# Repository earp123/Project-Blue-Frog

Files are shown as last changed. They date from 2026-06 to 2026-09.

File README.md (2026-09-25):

# nRF5340 LoRa Field-Test Device (SX1262)

An open-source field-test device for **long-distance LoRa radio work**, built
around the Nordic **nRF5340** and a Semtech **SX1262** sub-GHz radio. It
currently hosts the radio layer of a sports-officials intercom: a fixed
4-slot TDMA broadcast flood in which every unit transmits once per frame and
hears everyone else.

Each unit pairs the radio with a local display and an SD card, so it is both
a link **endpoint** and an **instrument**: it runs timed soak tests, shows
live link telemetry, and logs every packet to SD for offline decoding. Build
two to four and you have a real multi-unit link to characterise in the field.

 

For the design history, measured results and known limitations, see
[CHANGELOG.md](CHANGELOG.md).

## Contents

- [Unit types](#unit-types)
- [Building and flashing](#building-and-flashing)
- [Using a unit](#using-a-unit)
- [Radio parameters](#radio-parameters)
- [LoRa radio shield (TFT unit)](#lora-radio-shield-tft-unit)
- [Rev 2 shield (shield unit)](#rev-2-shield-shield-unit)
- [TFT front end (TFT unit)](#tft-front-end-tft-unit)
- [SDK setup (fresh from Nordic)](#sdk-setup-fresh-from-nordic)

## Unit types

The tree builds one firmware per unit type. Both run the same TDMA radio
layer ([`src/tdma/`](src/tdma)) and the same SD soak logger, on an nRF5340
DK.

| Unit | Hardware | Firmware | Overlay + conf |
|---|---|---|---|
| **TFT unit** | Radio shield (rev 1) on Port 1, plus the Hiletgo ILI9341 TFT breakout (touch + microSD) jumper-wired to Port 0 | `CONFIG_APP_TDMA_CONSOLE`, [`src/tdma_console/`](src/tdma_console) | `boards/nrf5340dk_nrf5340_cpuapp_tft.{overlay,conf}` |
| **Shield unit** | Rev 2 shield: SX1262 + SSD1306 128×64 OLED + microSD in one stack | `CONFIG_APP_TDMA_FIELD`, [`src/tdma_field/`](src/tdma_field) | `boards/nrf5340dk_nrf5340_cpuapp_shield.{overlay,conf}` |

- **TFT unit:** touch + DK-button UI on the TFT. Display-only: no UART.
- **Shield unit:** button-only cycle-menu UI on the OLED. UART logging is on
  over the DK's VCOM.

The two types interoperate on air and can be mixed freely in one kit.

## Building and flashing

Each unit type needs **both** of its files, the overlay and the conf,
passed together. A build with only one of them, or neither, stops at CMake
with these two lines. Use `-p always` (pristine) when switching types.

```sh
# TFT unit
west build -b nrf5340dk/nrf5340/cpuapp -p always -d build-tft -- \
  -DEXTRA_DTC_OVERLAY_FILE=boards/nrf5340dk_nrf5340_cpuapp_tft.overlay \
  -DEXTRA_CONF_FILE=boards/nrf5340dk_nrf5340_cpuapp_tft.conf

# Shield unit
west build -b nrf5340dk/nrf5340/cpuapp -p always -d build-shield -- \
  -DEXTRA_DTC_OVERLAY_FILE=boards/nrf5340dk_nrf5340_cpuapp_shield.overlay \
  -DEXTRA_CONF_FILE=boards/nrf5340dk_nrf5340_cpuapp_shield.conf
```

The board-named radio overlay (`nrf5340dk_nrf5340_cpuapp.overlay`) is applied
automatically in both builds.

Flash with the DK's J-Link serial number when more than one board is on USB
(`nrfutil device list` shows them):

```sh
west flash -d build-shield --dev-id <serial>
```

> [!NOTE]
> A DK that arrives with readback protection (APPROTECT) refuses to attach.
> `west flash --recover` fixes it once, and **erases all flash on both
> cores**. These builds leave debug access open, so later flashes work
> normally. `west flash` defaults to the `nrfutil` runner, which needs its
> `device` command (`nrfutil install device`); `-r jlink` also works.

## Using a unit

Both types behave the same way:

- **Power-on unit pick (mandatory).** Choose **MASTER** (slot 0) or **SEC 1**,
  **SEC 2** or **SEC 3**. This sets the role and the TX slot together. The
  master beacons the frame timing, and each secondary locks to it. Every
  unit in a kit needs its own slot. The choice holds until reboot. The TFT
  unit runs a touch calibration first.
- **SOAK:** pick 5 min, 30 min, 2 h or continuous. Live pages show elapsed
  time, TX/stale, RX with missed/duplicate frames, phase error and ppm,
  RSSI/SNR, the log file, and the staging-latency gauge.
- **TX power:** −9…+22 dBm, applied from the next packet. The TFT unit boots
  at +22 dBm and the shield unit at +0 dBm.
- **SD logging:** every soak writes `<PWR>_<DUR>_NNN.BIN` (e.g.
  `P0_5M_000.BIN`) with one 64-byte record per packet. Decode with
  [`src/tdma_console/tools/decode_soak_log.py`](src/tdma_console/tools/decode_soak_log.py).
  Each file's header records the unit's role and slot.
- **Buttons:** B1 = UP, B2 = DOWN, B3 = OK, B4 = BACK. On the shield unit, B4
  also stops a running soak.

> [!IMPORTANT]
> **Reboot after swapping an SD card.** Card detect is read by the app only,
> so a card changed while mounted is never re-initialised, and every write
> then fails. The shield unit's socket is push-push: it makes no contact
> until it clicks.

## Radio parameters

Fixed in [`src/tdma/tdma.h`](src/tdma/tdma.h); only TX power is adjustable
at runtime.

- Frequency: 915.0 MHz, single channel
- LoRa SF5 / BW 500 kHz / CR 4/5, explicit header, CRC on
- Preamble: 12 symbols (the SX1262 minimum for SF5)
- Packet: 44 bytes (4-byte TDMA header + 40-byte payload), 7,760 µs on air
- Frame: 4 slots × 20 ms = 80 ms. Master in slot 0, secondaries in 1–3.

---

## LoRa radio shield (TFT unit)

The SX1262 (Wio-SX1262) is mounted on a custom Arduino-form-factor shield that
routes its signals to the nRF5340 DK Port 1 header section. The rev 2 shield
keeps exactly the same radio pins.

### Wiring (nRF5340 DK → Wio-SX1262)

| Signal | nRF5340 pin | Wio-SX1262 pin |
| --- | --- | --- |
| SPI SCK  | P1.05 | SCK |
| SPI MOSI | P1.04 | MOSI |
| SPI MISO | P1.01 | MISO |
| SPI CS | P1.07 | NSS |
| RESET | P1.06 | RESET |
| BUSY | P1.09 | BUSY |
| DIO1 | P1.08 | DIO1 |
| RF_SW | P1.00 | RF_SW |
| VCC | 3V3 | VCC (+ 33µF cap) |
| GND | GND | GND |

Notes:

- **RF_SW** (P1.00) is driven by the firmware as a GPIO output and held LOW
  (at GND) for both TX and RX on this module. This is the correct level for the
  Wio-SX1262 antenna switch — it does not need to be toggled.
- **DIO2** is internally bridged to TXEN on the Wio-SX1262 — no external wiring.
  `dio2-tx-enable` in the overlay lets the chip drive TXEN itself.
- **DIO3** drives the onboard TCXO — no external wiring; configured via
  `dio3-tcxo-voltage`.
- **uart1** is disabled in the overlay so that P1.01 is free for MISO.
- **33µF decoupling capacitor** on the Wio-SX1262 VCC pin is required. The TX
  current transient on the SX1262 power amplifier causes a supply droop
  sufficient to cause intermittent TX failures without it.

Devicetree (`nrf5340dk_nrf5340_cpuapp.overlay`, SX1262 node):

```dts
lora: sx1262@0 {
    compatible = "semtech,sx1262";
    reg = <0>;
    reset-gpios    = <&gpio1 6 GPIO_ACTIVE_LOW>;
    busy-gpios     = <&gpio1 9 GPIO_ACTIVE_HIGH>;
    dio1-gpios     = <&gpio1 8 GPIO_ACTIVE_HIGH>;
    dio2-tx-enable;
    dio3-tcxo-voltage = <SX126X_DIO3_TCXO_1V8>;
    tcxo-power-startup-delay-ms = <10>;
    spi-max-frequency = <500000>;
};
```

The radio is selected through the `lora0` alias; `RF_SW` is exposed via the
`zephyr,user` node's `rf-sw-gpios` property (P1.00). The native Zephyr driver
only initialises the chip; the TDMA layer owns it after that.

---

## Rev 2 shield (shield unit)

One Arduino-form-factor board carrying the Wio-SX1262 (same pins as above),
a 0.96" SSD1306 OLED and a push-push microSD socket. Fabrication data:
[`Hardware/OLED-SD-SX1262-Shield_2026-08-16.zip`](Hardware/OLED-SD-SX1262-Shield_2026-08-16.zip).
All pins were traced in its netlist and confirmed on the bench.

| Device | Bus | Pins (DK Arduino header) |
|---|---|---|
| microSD | spi4 | SCK **P1.14** (D12), MOSI P1.13 (D11), MISO **P1.15** (D13), CS P1.11 (D9), card-detect P1.12 (D10, active low) |
| SSD1306 128×64 | i2c1 @ 400 kHz | SDA P0.25 (A4), SCL P0.26 (A5), RST P0.07 (A3), address 0x3C |

- **SD SCK/MISO are the reverse of the DK's own `arduino_spi`.** That is how
  the board is routed.
- **The OLED is on A4/A5.** The R3 header's dedicated SDA/SCL pins are not
  connected.
- **No I2C pull-ups on the shield.** The overlay enables the nRF's internal
  ones as a fallback.
- **The I2C driver's concat buffer is raised to 1025 bytes** (a control byte
  plus a full frame). With the 16-byte default, every frame write fails and
  the screen stays blank.

---

## TFT front end (TFT unit)
[https://a.co/d/047jULLv](url)
The TFT unit's front end — ILI9341 TFT, XPT2046 touch, microSD — shares one
SPI bus (**spi4**, the DK's high-speed `arduino_spi` instance on Port 0),
distinct from the radio's spi2 on Port 1. Each device has its own chip
select. **These signals are jumper-wired to the DK Arduino headers.**

### Pin assignments

| Signal | nRF5340 pin | Device pin |
| --- | --- | --- |
| SPI SCK | P0.13 | SCK (all) |
| SPI MOSI | P0.14 | MOSI/SDI (all) |
| SPI MISO | P0.15 | MISO/SDO (all) |
| LCD CS | P0.16 | ILI9341 CS |
| LCD D/C | P0.17 | ILI9341 D/C |
| LCD RESET | P0.18 | ILI9341 RESET |
| LCD backlight | P0.31 | Backlight (active high) |
| TOUCH CS | P0.28 | XPT2046 CS |
| TOUCH IRQ | P0.29 | XPT2046 IRQ (active low, pull-up)|
| SD CS | P0.10 | microSD CS |

CS lines are indexed by each device's `reg` on the spi4 node: reg 0 = display
(P0.16), reg 1 = touch (P0.28), reg 2 = SD (P0.10).

> [!IMPORTANT]
> **nRF5340 DK board modifications required.** Several of these Port 0 pins are
> wired to on-board peripherals on the DK and must be freed before the front end
> works. The relevant solder bridges are marked on the DK silkscreen (and
> detailed in the nRF5340 DK Hardware User Guide); the exact `SBxx` designators
> vary by board revision.
>
> - **SPI bus — P0.13–P0.18 are shared with the on-board QSPI flash** (MX25R64).
>   SPI SCK/MOSI/MISO and LCD CS / D-C / RESET land on the flash's
>   `QSPI_IO0/IO1/IO2/IO3` + `QSPI_SCK`/`QSPI_CSN`, so the flash must be
>   **disconnected** (cut its solder bridges) — otherwise it loads and contends on
>   the shared bus.
> - **P0.28–P0.31 are the four on-board LEDs** (LED1–LED4). The front end uses
>   P0.28 (touch CS), P0.29 (touch IRQ), and P0.31 (backlight); P0.30 (LED3) is
>   unused. Isolate these LEDs from the GPIOs (per the silkscreen bridges) so the
>   on-board LEDs don't interfere with the touch/backlight lines.
>
> The four DK buttons (P0.23/24/08/09) are **not** modified — they still drive the
> menu UI.

### Implementation notes / deviations

- **Touch binding is** `xptek,xpt2046` (not `ti,tsc2046`) in this Zephyr. It
  reports via the input subsystem (`INPUT_ABS_X/Y`, `INPUT_BTN_TOUCH`); the
  IRQ is edge-to-active (falling, `GPIO_ACTIVE_LOW | GPIO_PULL_UP`).
- **ILI9341 RESET is active-low.** The MIPI-DBI driver leaves reset de-asserted
  after its pulse, so `reset-gpios` must be `GPIO_ACTIVE_LOW` — otherwise the
  panel is held in reset and stays blank even though SPI writes "succeed".
- **CFB cannot drive the ILI9341.** Zephyr's character framebuffer is
  monochrome-only (1 bpp); the ILI9341 is RGB565/RGB888. The app enables CFB only
  to link its (correct) bundled font glyph data, then blits that into RGB565
  itself with `display_write()` (white/black, byte-order agnostic).
- The display uses the **MIPI DBI** subsystem: a `zephyr,mipi-dbi-spi`
  controller wraps spi4 and owns the D/C and RESET sidebands; the
  `ilitek,ili9341` node sits under it.
- **Drawing stays single-owner.** Input callbacks only set atomics; the main
  loop does every `display_write()`. Touch taps are debounced (one event per
  press, release required) before the loop consumes them.
- **Touch is calibrated by an on-device affine fit**
  (`src/tdma_console/touch_cal.c`). Raw XPT2046 coordinates are offset /
  swapped / inverted relative to the display; a 6-parameter affine corrects
  all of it at once. Calibration is a mandatory power-on step: five crosshair
  taps, a least-squares fit, then a verify step. The fit lives in RAM only.

---

## SDK setup (fresh from Nordic)

This project uses the **native** Zephyr SX126x LoRa driver
(`CONFIG_LORA_MODULE_BACKEND_NATIVE` / `CONFIG_LORA_SX126X_NATIVE`), which is
**not part of stock NCS v3.2.1**. Two repo assets close that gap so the project
builds against a clean SDK:

- `external/zephyr-lora-driver/` — the newer Zephyr `drivers/lora/`
  subsystem (incl. the native SX126x driver), vendored verbatim.
- `patches/` — small compat patches: SPI macro arity (`0001`), the
  `regulator-ldo` / `force-ldro` binding properties (`0002`), and the newer
  `lora.h` API the driver expects (`0003`).

### Onboarding (what to do with a fresh Nordic SDK)

1. Install **NCS v3.2.1 + toolchain** via nRF Connect for Desktop → *Toolchain
   Manager* (provides `west`, CMake, Ninja, the Zephyr SDK/GCC). Install
   **SEGGER J-Link** too (the DK's on-board debugger).

2. Prepare the SDK from this repo (idempotent; defaults `ZEPHYR_BASE` to
   `C:/ncs/v3.2.1/zephyr`):

   ```sh
   ZEPHYR_BASE=/path/to/ncs/zephyr ./scripts/setup_sdk.sh
   ```

   This swaps the vendored `drivers/lora/` into the SDK (backing up the stock
   one to `drivers/lora.stock.bak`) and applies the patches.

3. Build one of the two unit types and flash it, as shown in
   [Building and flashing](#building-and-flashing).

**Symptoms if the SDK was not prepared:**

- `macro "SPI_DT_SPEC_INST_GET" requires 3 arguments, but only 2 given`
- `'..._P_regulator_ldo' undeclared` / `'..._P_force_ldro' undeclared`
- silently building the wrong LoRa backend (the native `CONFIG_*` symbols
  don't exist on a clean SDK and are dropped with a warning)

> [!WARNING]
> These changes live in the NCS install, not in this repo. Any `west update`,
> SDK reinstall, or Toolchain Manager repair reverts them — just re-run
> `scripts/setup_sdk.sh` and do a pristine build. Patch 2 changes a
> devicetree binding, which is only picked up on a CMake reconfigure
> (`-p always`).

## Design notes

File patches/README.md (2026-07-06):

# Vendored NCS SDK patches

These patches make this project's **native SX126x LoRa driver** build against
**NCS v3.2.1**. They modify files **inside the NCS install** (`$ZEPHYR_BASE`),
not this repository — so they are vendored here and applied with a script.

## Apply

> [!TIP]
> **New here?** Run [`scripts/setup_sdk.sh`](../scripts/setup_sdk.sh) instead — it
> installs the vendored driver *and* runs `apply.sh` for you. Use `apply.sh`
> directly only to re-apply the patches when the native driver is already present
> (see [Prerequisite](#prerequisite-the-vendored-lora-driver) below).

```bash
# defaults ZEPHYR_BASE to C:/ncs/v3.2.1/zephyr
ZEPHYR_BASE=/path/to/ncs/zephyr ./patches/apply.sh
```

The script is idempotent (skips already-applied patches) and uses `git apply`
against the NCS `zephyr/` checkout. After applying, do a **pristine** build
(`west build -p always`) — Patch 2 changes a devicetree binding, which is only
picked up on a CMake reconfigure.

## What they fix

`west build` fails without these with:

- `macro "SPI_DT_SPEC_INST_GET" requires 3 arguments, but only 2 given`
- `'..._P_regulator_ldo' undeclared` / `'..._P_force_ldro' undeclared`
- `'SF_5' undeclared` / `'BW_7_KHZ' undeclared` /
  `'struct lora_modem_config' has no member named 'packet_crc_disable'` /
  `'struct lora_driver_api' has no member named 'recv_duty_cycle_async'`

| File | Patch | Why |
|---|---|-----|
| `0001-native-sx126x-spi-dt-spec-arity.patch` | adds the trailing `delay` arg (`0`) to both `SPI_DT_SPEC_INST_GET` calls in `drivers/lora/native/sx126x/sx126x.c` | the native driver uses the newer 2-arg SPI macro; v3.2.x's `spi.h` requires 3 args |
| `0002-sx126x-base-binding-add-ldo-props.patch` | adds the `regulator-ldo` and `force-ldro` boolean properties to `dts/bindings/lora/semtech,sx126x-base.yaml` | the native driver reads these DT props, which don't exist in v3.2.x's binding |
| `0003-lora-h-native-driver-api-compat.patch` | brings `include/zephyr/drivers/lora.h` up to the newer upstream API the vendored driver was written against: `SF_5`, the narrow `BW_*` enum members, `packet_crc_disable`, and the `recv_duty_cycle_async`/`airtime` driver-API slots + inline wrappers | stock v3.2.x ships the older LoRa API header; the vendored driver **and this project's app sources** (`SF_5` etc.) don't compile against it |

Note: `apply.sh` passes `--ignore-whitespace` to `git apply`. On Windows the
repo checkout is CRLF (`.gitattributes` `text=auto`), so the driver files
`setup_sdk.sh` copies into the SDK carry CRLF while the patches are LF;
without the flag none of the patches match their context.

## Prerequisite: the vendored LoRa driver

These patches assume the **newer native LoRa driver is present** in the SDK
(`drivers/lora/native/`). That driver is **not** part of stock NCS v3.2.1, so it
is vendored in `../external/zephyr-lora-driver/` and installed by
`../scripts/setup_sdk.sh`, which copies it into `$ZEPHYR_BASE/drivers/lora` and
*then* runs `apply.sh`.

**For a fresh-from-Nordic SDK, run `scripts/setup_sdk.sh` — not `apply.sh`
directly.** `setup_sdk.sh` does the driver swap first; `apply.sh` only patches
and will refuse to run if the native driver is absent.

## Caveat: these revert on SDK changes

Any `west update`, SDK reinstall, or Toolchain Manager repair reverts these
edits **and the vendored driver swap**. Re-run
[`scripts/setup_sdk.sh`](../scripts/setup_sdk.sh) afterward — running `apply.sh`
alone is not enough, since it refuses once the native driver is gone.

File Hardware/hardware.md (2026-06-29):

hardware entry file

Pictured in the readme. I spun these shields at OSH Park and assembled the radio chip by hand.

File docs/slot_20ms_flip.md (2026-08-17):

# Task: flip `TDMA_SLOT_DURATION_US` to 20 ms + acceptance soak

**Status:** ready. **Decisions (2026-08-16):** straight constant flip (no runtime
selector first); `frame_ctr` wrap fix deferred — soaks at 20 ms capped under
1.4 h; units 3/4 not yet available — this task validates on the 2-unit bench,
the 4-unit soak and field campaign are gated on hardware.

## The change

`src/tdma/tdma.h`:

```diff
-#define TDMA_SLOT_DURATION_US	50000
+#define TDMA_SLOT_DURATION_US	20000
```

Everything else derives or is width-independent, verified at head:

| Constant | At 20 ms | Check |
|---|---|---|
| `TDMA_FRAME_DURATION_US` | 80 ms (derived, 4 slots) | beacon cadence 12.5 Hz |
| `TDMA_SLOT_ACTIVE_US` | 18 ms (derived, 90%) | > 8.3 ms worst in-slot completion (532 + 7760) — TX timeout only, RX is continuous |
| `TDMA_TOA_US`, `TDMA_TX_START_LATENCY_US` | unchanged | width-independent; `dtx` = 8292 µs is the regression check |
| `TDMA_SYNC_STEP_CLAMP_US` | 500 µs **per 80 ms frame** | max slew 6.25 ms/s (was 2.5) — intended, no change |
| `TDMA_RX_MSGQ_DEPTH` | 32 | header comment already sizes this for the 20 ms 4-unit case |

## Pre-flight audit (before flashing)

1. Confirm every `tdma_config.slot_duration_us` initializer in the app variants
   passes the macro, not a literal — `tdma_init()` rejects a mismatch.
2. Comment touch-up in `tdma.h`: the per-slot tallies comment says "the
   programmed 45 ms" (the 50 ms-era `SLOT_ACTIVE`); make it width-neutral.
   The `TDMA_SLOT_DURATION_US` comment's "test-build / production target"
   framing inverts with the flip — update it.
3. No soak-preset code change. Constraint recorded instead: at 20 ms the
   counter wraps at **1.46 h**. Within-file continuity is wrap-safe (modular
   deltas); absolute cross-file alignment past a wrap is not. Until the wrap
   card closes: use the 5 min / 30 min / 1 h-equivalent presets for anything
   needing cross-file pairing; a continuous run is valid but only
   pairwise-alignable up to the first wrap.

## Acceptance soak

30 min preset, 20 ms slots, both bench units, +0 dBm (same as the 250 µs
threshold soak, for comparability), SD-logged both sides, decode both files.

Rate sanity: 2 units at 80 ms frames = 1 TX + 1 RX record per frame per unit
= 25 rec/s = 1.6 KB/s — half the SD budget.

**Pass criteria** (50 ms baselines in parentheses):

- Lock: SYNCING → RUNNING within single-digit seconds (2.3 s). The one
  failure mode the one-way transition allows is *slow or absent lock* — a
  unit stuck in SYNCING fails the soak regardless of anything else.
- `dtx` = 8292 ± tens of µs, **both roles** (8292 exactly); `drx` collapses
  to the same value on both (8290/8291).
- `phase_err`: median ≈ 0, p95 |err| ≤ 50 µs (24 µs), worst |err| < 125 µs —
  half the 250 µs bar. Beacons arrive 2.5× more often, so equal-or-tighter
  is the expectation; growth toward the bar is a red flag even if it locks.
- Link: PER 0.000%, 0 missed / 0 dup, 0 `seq` gaps, `stale_retx` /
  `busy_timeouts` / `slot_timeouts` all 0 (all match the 11-min baseline).
- `ppm`: mean within a few ppm of −6.9 (same crystal pair). Per-sample σ up
  to ~170 is *expected*, not a regression — the estimator divides the same
  ±13 µs timestamp jitter by an 80 ms frame instead of 200 ms. The mean is
  the signal.

## Out of scope / gated

- **4-unit soak**: gated on building units 3 and 4. The open re-validation
  question (three peer slots between corrections during acquisition) can only
  be answered there.
- **Field campaign at 20 ms**: after the 4-unit bench soak.
- **`frame_ctr` widen/unwrap** and **runtime slot-width selector**: separate
  cards, unchanged by this task.

## CHANGELOG

New entry: slot width 50 → 20 ms with the soak results and the pass/fail
table above; note the 1.4 h soak-duration constraint at 20 ms and reference
the wrap limitation. Update the "what remains before calling 20 ms proven"
line to: 4-unit soak (hardware pending) + field campaign.

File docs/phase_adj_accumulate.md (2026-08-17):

# Task: make `tdma_port_add_phase_adj()` accumulate

**Status:** ready for implementation. **Scope:** one semantic fix + comment updates + CHANGELOG. No behavior change for the current call pattern.

## Context

`tdma_port_add_phase_adj()` in `src/tdma/tdma_port.c` is named "add" but implements *set*:

```c
void tdma_port_add_phase_adj(int32_t adj_us)
{
	atomic_set(&phase_adj_us, adj_us);
}
```

The consumer is `slot_alarm_cb()`, which folds the entire pending value into one boundary:

```c
next_target += slot_ticks + (uint32_t)atomic_clear(&phase_adj_us);
```

With overwrite semantics, any second post before the next boundary silently discards the first. This is **latent today**: `tdma_core_sync_feed()` posts exactly one correction per beacon (one per frame), and boundaries consume 4x per frame, so there is never more than one outstanding value — set and add are currently indistinguishable. It becomes a real bug the moment two posts can land between consumptions (a slew-limited loop splitting a large error into partial steps, or a drift/ppm feed-forward writer added alongside the beacon correction — both on the table for the M3 filter work). A dropped correction self-heals at the next beacon but is transiently wrong; at 20 ms slots with `TDMA_SYNC_LOCK_ERR_US` tightened to ~250 us, a dropped ms-scale correction can bounce a unit out of RUNNING.

## Change

`src/tdma/tdma_port.c`:

```diff
 void tdma_port_add_phase_adj(int32_t adj_us)
 {
-	atomic_set(&phase_adj_us, adj_us);
+	atomic_add(&phase_adj_us, adj_us);
 }
```

Notes for the implementer:

- **Behavior-identical for the current single-post pattern**: adding to a zeroed pending value equals setting it. The acquisition snap (`fwd` up to one frame) and the steady-state clamped step both still apply in full at the next boundary.
- **Race with the consumer is benign under add**: a post either lands before the ISR's `atomic_clear` (applied at this boundary) or after (pending for the next). Nothing is ever lost. This was also true under set for a single writer; add extends the guarantee to any number of posts.
- The `(uint32_t)` cast on the consumer side stays — negative adjustments work through two's-complement wraparound on the unsigned add, as today.
- `tdma_port_schedule_start()` already zeroes `phase_adj_us` before arming; unchanged.

## Comment updates (same commit)

1. `src/tdma/tdma_port.h` — the contract comment on `tdma_port_add_phase_adj()`: state that corrections **accumulate** into a single pending value consumed in full at the next slot boundary, and that multiple posts between boundaries sum.
2. `src/tdma/tdma_port.c` — the `slot_alarm_cb()` block comment currently reads "A pending sync correction is folded in once." Amend to: pending corrections accumulate and the sum is folded in once.

## Explicitly out of scope

**No consumption-side per-boundary clamp.** Post-side clamping already exists where it matters: the steady-state step is clamped to `+/-TDMA_SYNC_STEP_CLAMP_US` at the call site in `tdma_core_sync_feed()`, and the acquisition snap is deliberately unclamped and forward-only (see its comment — a clamped loop would take tens of seconds to pull in a worst-case offset, and forward-only guarantees the alarm target never lands in the past). Slewing the snap at the consumer would fight that design. A per-boundary application clamp belongs with the M3 sync-filter rework (`TODO(M3+)` in `tdma_core_sync_feed()`), where multiple partial posts per frame become a real pattern.

## Verification

1. Build the TDMA field console variant; flash both bench units.
2. Cold start: secondary acquires and locks in the usual ~6 s (snap behavior unchanged).
3. 10+ min soak at 50 ms: `ph` converges to single-digit us as before; `dtx`/`drx` hold ~8292 us; no new `stale_retx` or slot timeouts.
4. Behavior must be indistinguishable from the previous build — this change is semantic future-proofing, not a tuning change.

## CHANGELOG

Mark the 2026-07-21 open item ("`tdma_port_add_phase_adj()` overwrites rather than accumulates a pending correction") resolved with the date, and note the accumulate semantics under a new entry. This is step 3 (first half) of the 50 ms -> 20 ms tightening sequence; the `TDMA_SYNC_LOCK_ERR_US` tightening to ~250 us follows as a separate change once this soaks clean.

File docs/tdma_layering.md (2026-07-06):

# TDMA layering findings (M0)

Verification record for the intercom TDMA variant's four-layer architecture:
what the native driver (L0) actually does, how the app-owned command layer
(L1) and TDMA engine (L2) coexist with it, and what was found when auditing
the driver for autonomous runtime behaviour. File/line references are into
the vendored driver (`external/zephyr-lora-driver/drivers/lora/native/sx126x/`),
which is byte-identical to the installed copy under `$ZEPHYR_BASE/drivers/lora`
(modulo line endings) by construction of `scripts/setup_sdk.sh`.

## Where the native driver landed on this machine

- SDK in use: **NCS v3.2.0** at `C:/ncs/v3.2.0/zephyr` (the repo README says
  v3.2.1; this machine has v3.2.0 and v3.3.0 installed, and the nRF Connect
  toolchain bundle `66cdf9b75e` serves both v3.2.0 and v3.2.1). Set
  `ZEPHYR_BASE=C:/ncs/v3.2.0/zephyr` when running `scripts/setup_sdk.sh`.
- The vendored `drivers/lora` tree was already installed there, but the
  compat patches were **not** applied — `git apply` refused them because the
  Windows checkout (`.gitattributes` `text=auto`) copies CRLF files into the
  SDK while the patches are LF. `patches/apply.sh` now passes
  `--ignore-whitespace`, which resolves this; it also globs all numbered
  patches instead of naming 0001/0002.
- Stock NCS v3.2.0's `include/zephyr/drivers/lora.h` predates the vendored
  driver and lacks `SF_5`, the narrow `BW_*` members, `packet_crc_disable`,
  and the `recv_duty_cycle_async`/`airtime` API slots. **No variant of this
  project compiled against it.** New patch
  `patches/0003-lora-h-native-driver-api-compat.patch` brings the header up
  to what the vendored driver (and the existing console/lora-send sources)
  expect, mirroring the newer upstream layout. All three firmware variants
  build after `setup_sdk.sh`.

## L0 driver: DIO1 mechanism and the detach

The driver's interrupt path (the one autonomous runtime SPI path):

- `sx126x_hal_init()` registers a `struct gpio_callback` on the DIO1 pin:
  `gpio_init_callback(&data->dio1_cb, dio1_isr, ...)` + `gpio_add_callback()`
  (`sx126x_hal.c:160-161`). The callback struct lives in driver data:
  `((struct sx126x_data *)dev->data)->hal.dio1_cb` (`sx126x_hal.h:41-45`,
  `sx126x.h:35-36`).
- `dio1_isr` forwards to `data->dio1_callback`, which the driver sets to
  `sx126x_dio1_callback` (`sx126x.c:1479`); that handler does
  `k_work_submit(&data->irq_work)` (`sx126x.c:559-564`) and
  `sx126x_irq_work_handler` performs **SPI transactions on the system
  workqueue** (`sx126x.c:800-834`) — exactly the violation of L2's sole-SPI-
  ownership invariant that had to be neutralized.

**Detach method used:** `gpio_remove_callback()` on the driver's callback
struct, which *is* reachable — `tdma_radio.c` includes the driver-internal
`sx126x.h` (include path added in `CMakeLists.txt` pointing at the installed
copy in `$ZEPHYR_BASE`) and removes `&drv_data->hal.dio1_cb` from the DIO1
port, then registers the TDMA port's own callback and re-enables the pin
interrupt. No `patches/0003`-style detach hook was needed for this. After
removal the driver cannot regain the pin: `gpio_add_callback` for its struct
only happens in `sx126x_hal_init()` (device init), and
`sx126x_hal_set_dio1_callback()` only flips the function pointer and the pin
interrupt config, not the callback registration.

Ordering (in `tdma_radio_init()`): `device_is_ready()` → `lora_config()` →
detach + attach → remaining L1 init → `k_sem_give(&tdma_spi_bus_sem)`. The
radio thread's first act is taking that semaphore, held forever.

## Does `lora_config()` calibrate the image post-TCXO?

**Yes.** `sx126x_chip_init()` (driver device init) configures the TCXO via
DIO3 and runs `Calibrate(ALL)` after it (`sx126x.c:476-490`), and
`sx126x_lora_config()` additionally runs `sx126x_calibrate_image(dev,
config->frequency)` on every call (`sx126x.c:878-882`) with the correct
902-928 MHz band bytes (0xE1/0xE9) for 915 MHz (`sx126x.c:218-220`). L1
therefore does **not** re-issue `CalibrateImage` at init;
`sx126x_cmd_calibrate_image()` exists in L1 for completeness.

## Autonomous-quiescence audit of the driver after init

Checked the whole vendored native driver for anything that could touch the
SPI bus or radio state without an explicit `lora_*` API call:

| Path | Finding |
| --- | --- |
| DIO1 `gpio_callback` → `k_work irq_work` | The one real violation; detached at init (above). `irq_work` is only ever submitted from the DIO1 callback (`sx126x.c:563`), so with the callback removed the work item is dead. |
| `k_timer` / delayed work | None in the driver. |
| PM hooks | `sx126x_pm_action` exists only under `CONFIG_PM_DEVICE` (`sx126x.c:1439-1453`), which is **off** in this build (verified in `.config`); it also only touches GPIOs, not SPI. |
| LoRa shell | `drivers/lora/shell.c` issues runtime `lora_*` calls, but `CONFIG_LORA_SHELL` is **off** (defaults n; the TDMA variant's `select SHELL` does not enable it — verified in `.config`). |
| Sleep-when-idle | `CONFIG_LORA_SX126X_NATIVE_SLEEP` **defaults y** and would have `lora_config()` put the chip to sleep on return (and detach/re-attach DIO1 on its own). The app Kconfig forces it **n** for `APP_TDMA_TEST`, so `lora_config()` returns with the chip in STDBY_RC, configured, and the driver idle. |

Conclusion: after `tdma_init()` completes, the only ways the driver could run
are `lora_*` API calls, which L2 never makes past init. The invariant is
temporal and now holds.

## `sx126x_cmd` (L1) devicetree wiring

`sx126x_cmd.c` resolves its own specs from the same `lora0` node
(`DT_ALIAS(lora0)` → `&lora` on spi2, per the auto-applied
`nrf5340dk_nrf5340_cpuapp.overlay`):

- `SPI_DT_SPEC_GET(RADIO_NODE, SPI_WORD_SET(8) | SPI_TRANSFER_MSB, 0)` —
  same word size/order/CS behaviour as the driver, 500 kHz per the overlay's
  `spi-max-frequency`. The Zephyr SPI subsystem serializes bus users, so
  L0-at-init and L1-at-runtime sharing spi2 is safe.
- `GPIO_DT_SPEC_GET(RADIO_NODE, busy_gpios)` (P1.09) — all BUSY gating lives
  in L1: every transaction is preceded by a bounded BUSY-low spin
  (`sx126x_cmd_wait_busy`, 20 ms budget, timeout is fatal to the engine and
  counted as `busy_timeouts`).
- `GPIO_DT_SPEC_GET(RADIO_NODE, dio1_gpios)` (P1.08) — exported to the port
  layer for the IRQ handover.
- RF_SW (P1.00, `zephyr,user` `rf-sw-gpios`) is configured output-LOW first
  thing in `tdma_radio_init()`, same as the console and lora-send variants.

Init details beyond the plan's M0 list, found necessary while verifying the
driver:

- The DS §15.1 TX-modulation workaround for 500 kHz BW (clear bit 2 of reg
  0x0889) is applied by the driver only in its send path, which is never
  called — L1 applies it once at init; the radio never sleeps so it sticks.
- The driver programs a 200 µs PA ramp in `lora_config()`; L1 re-issues
  `SetPaConfig` + `SetTxParams(+22 dBm, 40 µs)` to match the locked
  invariants.
- Init ends in STDBY_XOSC (TCXO running); `SetRxTxFallbackMode(FS)` keeps the
  PLL locked between slots thereafter.

## Slot timer

TIMER2 on the app core (free: no other user in any variant; the kernel tick
uses RTC1, BLE/802.15.4 live on the net core), enabled in the shared board
overlay with `prescaler = <4>` → 1 MHz, driven via the Zephyr counter API
(`CONFIG_COUNTER_NRF_TIMER`, selected by `APP_TDMA_TEST` via
`CONFIG_COUNTER`). `tdma_port_init()` verifies `counter_get_frequency() ==
1 MHz` at boot. One alarm channel re-arms itself from an accumulating
absolute target; the DIO1 callback timestamps edges with
`counter_get_value()` (software-read jitter: a few µs of GPIOTE ISR latency,
acceptable for the M2 proportional sync and documented in the plan).

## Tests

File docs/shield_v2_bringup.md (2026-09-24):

# Task: rev 2 shield bring-up — OLED + microSD field variant (`tdma_field`)

**Status:** ready. **Decisions (2026-09-24):** new variant, not a port of the
TFT console; OLED is an SSD1306 0.96" 128×64 on I2C; UI is the essentials
only (role, soak pick, TX power, SD summary); UART logging stays on for
bring-up; soak runner copied from the TFT console now, extracted to a shared
module as a follow-on card; DET is an app-read GPIO, not wired into the SD
driver. Branch `shield_v2`, cut from `TDMA_shim` at `3746f11`.

Read `CHANGELOG.md` (Unreleased) and `docs/tdma_layering.md` first. The
existing `nrf5340dk_nrf5340_cpuapp.overlay` (SX1262 on spi2 / port 1) is
auto-applied and unchanged; everything below is additive.

## Hardware (rev 2 shield on the nRF5340 DK, 3.3 V)

| Device | Bus | Pins |
|---|---|---|
| Wio-SX1262 | spi2 | unchanged (SCK P1.05, MOSI P1.04, MISO P1.01, CS P1.07, RST P1.06, BUSY P1.09, DIO1 P1.08, RF-SW P1.00) |
| microSD | spi4 | SCK **P1.14**, MOSI P1.13, MISO **P1.15**, CS P1.11, DET P1.12 |
| SSD1306 128×64 | i2c1 | SDA P0.25, SCL P0.26, RST P0.07, addr 0x3C |
| DK buttons / LEDs | gpio | board dts (`buttons` node: P0.23/P0.24/P0.08/P0.09; LEDs P0.28–31 now free) |

The TFT/touch bus (P0.13–18, P0.10, P0.28–31) is retired in this variant;
the display overlay/conf and `tdma_console` stay in the tree, untouched and
buildable.

> [!WARNING]
> Two pin facts are unverified against copper and are the only things that
> can stall day one. Each has a 30-second fallback — try it before debugging
> anything else.
> - **SD SCK/MISO.** The DK's default `spi4` (Arduino D13/D12) is SCK P1.15 /
>   MISO P1.14 — the reverse of the assignment above. If the card reports
>   `disk` failure, swap SCK and MISO in the pinctrl group first.
> - **OLED bus.** The R3 header's dedicated SDA/SCL pins are P1.02/P1.03,
>   not A4/A5. If nothing ACKs at 0x3C on P0.25/P0.26, try 0x3D, then move
>   i2c1's pinctrl to P1.02/P1.03.

## The change

### 1. Overlay — `boards/nrf5340dk_nrf5340_cpuapp_shield.overlay`

Passed via `EXTRA_DTC_OVERLAY_FILE` like the display overlay. Contents:

- `chosen { zephyr,display = &ssd1306; }`
- **spi4** re-pinned: new `spi4_sd_default` / `spi4_sd_sleep` pinctrl groups
  (SCK 1.14, MOSI 1.13, MISO 1.15); `cs-gpios = <&gpio1 11 GPIO_ACTIVE_LOW>`;
  the `sdhc0`/`mmc` nodes copied **verbatim** from the display overlay —
  `spi-max-frequency = <4000000>`, `power-delay-ms = <250>`, `disk-name =
  "SD"`. Those two values are the fix for the enumeration failures in the
  2026-07-31 findings; do not "tidy" them back to the binding defaults.
- **i2c1** re-pinned: `i2c1_oled_default` / `_sleep` (`TWIM_SDA` 0.25,
  `TWIM_SCL` 0.26), `clock-frequency = <I2C_BITRATE_FAST>`, and the SSD1306
  node taken from Zephyr's `boards/shields/ssd1306_128x64/` overlay
  (`solomon,ssd1306fb`, `reg = <0x3c>`, 128×64, `multiplex-ratio = <63>`,
  `segment-remap`, `com-invdir`, `prechargep = <0x22>`,
  `reset-gpios = <&gpio0 7 GPIO_ACTIVE_LOW>`).
- `zephyr,user { sd-det-gpios = <&gpio1 12 (GPIO_ACTIVE_LOW | GPIO_PULL_UP)>; }`
  — polarity is a guess (push-push socket, 10 k pull-ups on the shield); see
  test step 3. The node merges with the SX1262 overlay's `rf-sw-gpios`.

### 2. Conf — `boards/nrf5340dk_nrf5340_cpuapp_shield.conf`

Start from `nrf5340dk_nrf5340_cpuapp_tdma_console.conf`:

- `CONFIG_APP_TDMA_FIELD=y` (new Kconfig choice, see 3).
- Keep: `DISPLAY`, `CHARACTER_FRAMEBUFFER` (+ default fonts), `INPUT` +
  `INPUT_GPIO_KEYS`, the whole SD/FAT block including `FS_FATFS_EXFAT`,
  `FS_FATFS_LBA64` and **`FS_FATFS_MOUNT_MKFS=n`**, `MAIN_STACK_SIZE=8192`.
- Drop: `MIPI_DBI`. Add: `I2C=y` (SSD1306 selects it, but be explicit).
- **Do not** carry over the `SERIAL/CONSOLE/LOG=n` block. VCOM (P0.20/22) is
  no longer contended, so leave UART logging on for bring-up; stripping it is
  a follow-on once the variant is proven.

### 3. Variant — `CONFIG_APP_TDMA_FIELD`, `src/tdma_field/`

- `Kconfig`: add the choice entry (`select COUNTER`; help text names the
  shield overlay/conf); extend the `LORA_SX126X_NATIVE_SLEEP` default line
  and the CHANGELOG variant list.
- `CMakeLists.txt`: glob `src/tdma_field/*.c`; add
  `src/tdma_console/sd_log.c` and `src/tdma_console/soak_log.c` explicitly
  (both are display-agnostic — no `ui_widgets`/touch references) with
  `src/tdma_console` on the include path. Do **not** glob `src/tdma_console`
  or pull `ui_widgets.c`/`touch_cal.c` in.
- `src/tdma_field/main.c`: copy `soak_start` / `soak_finish` /
  `soak_data_step` / `soak_data_fn` / `soak_data_tid` and `button_cb` from
  `src/tdma_console/main.c` as-is (the data thread at `K_PRIO_COOP(6)` is
  what keeps staging off the UI loop — keep it). `soak_log_start()` is called
  with `dir = NULL` (root only, no drawers). Drawing goes through CFB
  (`cfb_print` / `cfb_framebuffer_finalize`) on the main loop at ≤ 2 Hz
  while a soak runs — a 1 KB frame at 400 kHz is ~25 ms of I2C on the UI
  thread and nothing else; the data thread is unaffected by construction.
  Use the CFB API as it exists in the NCS v3.2.1 tree (check
  `include/zephyr/display/cfb.h` before assuming signatures) and the
  smallest bundled font that gives ≥ 16 columns × ≥ 6 rows on 128×64.

### 4. UI — essentials only

Buttons keep the console's mapping: B1 UP, B2 DOWN, B3 OK, B4 BACK.

- **ROLE** (boot, mandatory): MASTER / SECONDARY, OK to confirm. Locks at the
  first `tdma_init()`, reboot to change — same semantics as the console.
- **HOME** (menu rows, header shows role + card state):
  - `SOAK` → sub-pick 5 min / 30 min / 2 h / continuous, OK starts.
  - `TX PWR` → UP/DOWN steps the value (−9…+22 dBm, clamp), stored for the
    next soak via `tdma_set_tx_power()`; default +0 dBm.
  - `SD` → count of `.BIN` files in the root, the newest file name, and free
    space if `fs_statvfs` is cheap to add as one more `sd_fsop` op on the
    writer thread. Read-only. Listing goes through `sd_fsop_submit(SD_FSOP_LIST,
    "/SD:", …)` + `sd_fsop_poll()` — never a direct FatFs call from the UI.
- **SOAK** (live): elapsed/limit, tx/stale, rx/miss/dup, phase_err/ppm,
  RSSI/SNR, log name + rec/drop (or `LOG FAIL <stage> <errno>`), the
  `lat N/51ms` gauge. B4 = STOP; the limit expiring ends the run exactly as on
  the console (data thread latches `expired`, UI performs the stop).
- Nothing else: no file browser, no drawers, no labels, no keypad, no
  touch-cal step.

## Test (in this order — stop at the first failure)

1. **Build.** All five existing variants plus `tdma_field` build with
   `-p always`. Build line for the new one:
   `west build -b nrf5340dk/nrf5340/cpuapp -p always -d build-tdma-field --`
   `-DEXTRA_DTC_OVERLAY_FILE=boards/nrf5340dk_nrf5340_cpuapp_shield.overlay`
   `-DEXTRA_CONF_FILE=boards/nrf5340dk_nrf5340_cpuapp_shield.conf`
2. **OLED.** Boot prints a splash line and the ROLE screen. Blank → the
   fallbacks in the warning above, in that order. Image offset by ~2 columns
   means the module is actually an SH1106: switch the compatible.
3. **SD.** On entering HOME, mount + `fs_statvfs`/list the root and show the
   result in the header. `disk` failure → swap SCK/MISO. Also log the raw DET
   level with and without a card and fix the polarity flag in the overlay.
4. **Radio.** 5-minute two-unit soak on the shield hardware at +0 dBm,
   decode both cards: `META slot=20000us` on both, lock in single-digit
   seconds, PER 0.000 %, 0 missed / 0 dup, `dtx` ≈ 8292 µs. This is the
   proof that the new bus assignments did not touch the radio path.

## Assess

If 1–4 pass, the shield is the field unit. Record the bring-up in the
CHANGELOG (new "Rev 2 shield / field variant" entry: pins, the two verified
pin facts, whether DET is active-low, soak numbers) and add the variant to
the Firmware variants list. While there: the 2026-08-17 slot-flip entry still
says the acceptance soak is outstanding, but Trello card #6 records it passing
on 2026-08-18 (`docs/P0_30M_000.BIN`, `s_P0_30M_001.BIN`, 22,480 frames each
way, 0 missed / 0 dup) — fold that result in so the CHANGELOG is the truth
again.

## Out of scope / follow-on cards

- Extract the soak runner (`soak_*` + data thread) into a shared module used
  by both consoles.
- Strip UART logging from the field variant once proven.
- `cd-gpios` on the sdhc node if this tree's `sdhc_spi` supports it.
- Card #23 (garbled first packet after lock) must land before the 4-unit
  soak; not part of this task.

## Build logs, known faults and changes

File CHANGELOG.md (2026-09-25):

# Changelog

All notable changes to this firmware are documented here. The format is loosely
based on [Keep a Changelog](https://keepachangelog.com/en/1.1.0/). The project is
pre-release, so the current development state lives under **Unreleased** until the
first tagged version.

For hardware wiring, build/flash instructions, and SDK setup, see
[README.md](README.md).

## [Unreleased]

On-device radio-evaluation tooling for the nRF5340 DK + Wio-SX1262 (SX1262),
plus the first slice of the wireless-intercom firmware (TDMA radio layer).
_Last updated: 2026-09-25._

### Firmware variants

Two variants, one per unit type on the bench, build from one source tree.
Exactly one `main()` is linked, chosen by the Kconfig choice in
[`Kconfig`](Kconfig) through the unit's companion conf. The README's
"Building and flashing" has both build lines.

- **TFT unit** (`CONFIG_APP_TDMA_CONSOLE`) —
  [`src/tdma_console/`](src/tdma_console) + the [`src/tdma/`](src/tdma)
  engine, built with `boards/nrf5340dk_nrf5340_cpuapp_tft.{overlay,conf}`.
  See "TDMA field console" below.
- **Shield unit** (`CONFIG_APP_TDMA_FIELD`) —
  [`src/tdma_field/`](src/tdma_field) + the same engine, built with
  `boards/nrf5340dk_nrf5340_cpuapp_shield.{overlay,conf}`. See "Rev 2 shield /
  field variant" below.

Four other variants were retired on 2026-09-25: LoRa send, the telemetry
console, the TDMA UART-shell test and the UART soak harness (see "Streamlined
to two unit types"). Their sections below are kept as history.

### Streamlined to two unit types (2026-09-25)

The bench now runs two kinds of radio, and the tree builds exactly those:

| Unit | Firmware | Files |
|---|---|---|
| TFT unit | `CONFIG_APP_TDMA_CONSOLE` | `boards/nrf5340dk_nrf5340_cpuapp_tft.overlay` + `.conf` |
| Shield unit | `CONFIG_APP_TDMA_FIELD` | `boards/nrf5340dk_nrf5340_cpuapp_shield.overlay` + `.conf` |

- **Removed:**
  - LoRa send (`src/main.c`).
  - The telemetry console: `src/console.c`, `radio_cfg`, `payload`,
    `pingpong` and `boards/..._display.conf`.
  - The TDMA UART-shell test (`src/tdma_app/`).
  - The UART soak harness (`src/soak/`).

  Their Kconfig entries went with them, including the TDMA test's
  role/slot/autostart options and the soak-test choice. Everything stays in
  git history.
- **One overlay + one conf per unit, with matching names.** The TFT pair was
  `display.overlay` + `tdma_console.conf`, and some builds also stacked the
  old telemetry console's `display.conf` on top. It is now `_tft.overlay` +
  `_tft.conf`.
- **A mismatched build stops at CMake.** If the unit's conf and overlay
  don't match, or are missing, the build fails with the two correct build
  lines rather than failing later in the link.
- **Shared code is built for both units.** The TFT-only `ui_widgets` and
  `touch_cal` moved into `src/tdma_console/`. The SD and soak loggers stay
  there too, and CMake builds them for both units.
  `LORA_SX126X_NATIVE_SLEEP` is now `n` unconditionally, and `prj.conf` only
  holds settings both units share.
- **No firmware change:** pristine builds of both units produce images the
  same size as before (TFT 103,064 B, shield 117,460 B).
- **README rewritten** around the two units: build and flash lines, the
  power-on unit pick, the rev 2 shield pins, and the SD hot-swap caveat.

### Rev 2 shield / field variant (2026-09-24)

The rev 2 shield carries the whole front end: SX1262 radio, a 0.96"
SSD1306 128×64 OLED and a push-push microSD socket. The TFT breakout is not
used. New variant `CONFIG_APP_TDMA_FIELD`; the TFT console is unchanged
apart from the unit pick. Its overlay/conf pair was renamed `_tft` on
2026-09-25.

| Device | Bus | Pins (DK Arduino header) |
|---|---|---|
| Wio-SX1262 | spi2 | unchanged: SCK P1.05, MOSI P1.04, MISO P1.01, CS P1.07, RST P1.06, BUSY P1.09, DIO1 P1.08, RF-SW P1.00 |
| microSD | spi4 | SCK **P1.14** (D12), MOSI P1.13 (D11), MISO **P1.15** (D13), CS P1.11 (D9), DET P1.12 (D10) |
| SSD1306 128×64 | i2c1 @ 400 kHz | SDA P0.25 (A4), SCL P0.26 (A5), RST P0.07 (A3), addr 0x3C |
| DK buttons / LEDs | gpio | board defaults; LEDs P0.28–31 are free again |

- **Pins traced in the fabrication data.** The two facts the task flagged as
  unverified were checked against the rev 2 board's ODB++ netlist
  ([`Hardware/OLED-SD-SX1262-Shield_2026-08-16.zip`](Hardware/OLED-SD-SX1262-Shield_2026-08-16.zip)).
  - **SD:** D12 → the socket's `SCLK` and D13 → `DO/DAT0`. SCK is P1.14 and
    MISO is P1.15, the reverse of the DK's default `arduino_spi`.
  - **OLED:** the header's SDA/SCL run to A4/A5 (P0.25/P0.26). The R3
    header's dedicated SDA/SCL pins (P1.02/P1.03) are unconnected.
  - **Radio:** D0–D7 carry the same nets as rev 1.

  All three were then confirmed on the bench (table below).
- **Netlist findings that affect bring-up:**
  - **DET:** the socket's `CD1` pad has a 100 k pull-up (R3) and a
    capacitor to GND. Its `CD2` pad is unconnected, but the switch still
    pulls `CD1` low when a card is seated, so DET works as-is.
  - **I2C pull-ups:** the shield has none on SDA/SCL. The overlay enables
    the nRF's internal pull-ups (~13 k) as a fallback. That is too weak for
    fast-mode rise times if the OLED module carries no pull-ups of its
    own; in that case drop to `I2C_BITRATE_STANDARD`.
  - **OLED header (JP1):** pin order is SDA, SCL, RST, GND, n/c, VCC.
- **Overlay** [`boards/nrf5340dk_nrf5340_cpuapp_shield.overlay`](boards/nrf5340dk_nrf5340_cpuapp_shield.overlay),
  passed via `EXTRA_DTC_OVERLAY_FILE`:
  - `spi4` re-pinned, with the SD slot on CS 0. The `sdhc`/`mmc` values are
    carried over from the display overlay: 4 MHz and `power-delay-ms =
    <250>`, the 2026-07-31 enumeration fix.
  - `i2c1` re-pinned, with the SSD1306 node from Zephyr's `ssd1306_128x64`
    shield plus the reset line. It also sets `zephyr,concat-buf-size =
    <1025>`. The SSD1306 driver sends each frame as a 1-byte control prefix
    plus 1024 pixel bytes, and TWIM has to merge the two in a RAM buffer
    that defaults to 16 bytes. With the default, the controller ACKed its
    init but every frame write failed and the screen stayed blank (+1 KB
    RAM).
  - `zephyr,user` gains `sd-det-gpios`, which the app reads; the SD driver
    does not.
- **Conf** [`boards/nrf5340dk_nrf5340_cpuapp_shield.conf`](boards/nrf5340dk_nrf5340_cpuapp_shield.conf):
  the TDMA console's SD/FAT block (exFAT, LBA64, `FS_FATFS_MOUNT_MKFS=n`),
  CFB, gpio-keys, a 2 KB heap for CFB's frame, and no `MIPI_DBI`. **UART
  logging stays on**, since this shield does not touch VCOM.
- **Soak runner** copied from the TFT console as-is: `soak_start` /
  `soak_finish` / `soak_data_step` and the `K_PRIO_COOP(6)` data thread.
  Logs always go to the card root. `sd_log.c`/`soak_log.c` are shared, not
  copied: CMake adds the two files by name, and their guards now accept
  either variant.
- **UI: a cycle menu.** One item per screen, drawn as large as it fits.
  The first cut packed 8 rows of 8×8 text onto the panel, which was
  unreadable on a 0.96" OLED. Each screen is now a caption line, one middle
  item and a detail line. B1/B2 cycle, B3 (OK) acts, B4 goes back.
  - **UNIT** at boot is mandatory: MASTER, SEC 1, SEC 2 or SEC 3 (see
    "Unit pick" below). The selection starts on SEC 1.
  - **HOME** cycles SOAK, TX PWR and SD CARD. The caption line shows the
    unit. Under SOAK, the detail line shows the card state (`SD 2 logs`,
    or `SD disk -116`), rescanned on every entry to HOME.
  - **SOAK** cycles 5 MIN, 30 MIN, 2 HOURS and CONTINUOUS. While a run is
    live, UP/DOWN cycle pages at 2 Hz: TIME, RX (miss/dup), TX (stale),
    PHASE (ppm), LINK (RSSI/SNR), LOG (file and records, or `LOG FAIL` with
    `<stage> <errno>`) and LAT (`N/51` ms). The caption shows run state and
    unit (`RUN M`, `SYNC S2`). B4 stops a run.
  - **TX PWR:** OK to edit, −9…+22 dBm, default **+0 dBm**.
  - **SD CARD** pages: `.BIN` count with the newest log, free/total space,
    and card detect (`CARD IN` / `NO CARD` with the raw level).

  UART logs boot, role, TX power, every card scan, every DET change, and
  a one-line summary of each run.
- **Card summary is a new writer-thread op**, `sd_fsop_submit_summary()`,
  rather than `SD_FSOP_LIST`. LIST stops at the caller's buffer and sorts
  by name. FAT appends new entries at the end of the directory, so a
  capped list drops exactly the newest logs. The new op walks the whole
  directory, counts `*.BIN`, keeps the last one in directory order, and runs
  `fs_statvfs`. A soak cannot start while a scan is in flight: the scan
  shares the writer thread with the log's open.
- **Fonts.** The caption and detail lines use CFB's 10×16 font, which fits
  12 characters, and every fixed string is written to fit that. The middle
  item takes the tallest font that fits, capped at 24 px so it stays clear
  of the edge lines. [`src/tdma_field/font_unscii8.c`](src/tdma_field/font_unscii8.c)
  adds an 8×8 font, unscii-8 (public domain), converted mechanically from
  LVGL's copy in the NCS tree by
  [`tools/gen_font_unscii8.py`](src/tdma_field/tools/gen_font_unscii8.py).
  It is now only a fallback for a runtime value too long for 12 characters.
- **Shared logger fix:** a write or close failure left `err_stage` blank, so
  the screen showed a bare errno. Those paths now report `write` / `close`,
  and each run starts with a clean stage. This affects the TFT console too.
- Build (FLASH 117,292 B / RAM 45,756 B):
  `west build -b nrf5340dk/nrf5340/cpuapp -p always -d build-shield --`
  `-DEXTRA_DTC_OVERLAY_FILE=boards/nrf5340dk_nrf5340_cpuapp_shield.overlay`
  `-DEXTRA_CONF_FILE=boards/nrf5340dk_nrf5340_cpuapp_shield.conf`

**Unit pick (both consoles).** Until now the TX slot followed the role:
master in slot 0, every secondary in slot 1. With three units, two
secondaries would transmit together in slot 1. The master would see
collisions, and the two secondaries would never hear each other. The
power-on role pick is now a **unit** pick, one choice per slot: MASTER
(slot 0) or SEC 1–3. It sets `tdma_config.slot_id`, the log's META slot and
the TX records' slot. The engine already accepted any slot 0–3; only the
master has to be in slot 0, because secondaries lock to its slot-0 beacon.
Order among secondaries does not matter as long as each has its own slot.
- **Field unit:** a cycle item (`UNIT 2/4`, `SEC 1`, `slot 1  OK`).
- **TFT console:** four touch/button choices under SELECT UNIT; buttons
  shrink from 90 to 48 px to fit.
- Both still let two units pick the same slot; that is on the operator.
- Three units stay under card #23's receive-buffer wrap. Each unit hears at
  most two packets between its own transmissions, and 2 × 44 B from 0x80
  ends at 0xD7. The spill onto the TX header needs a third, i.e. four units.

**Bench bring-up (2026-09-24, one rev 2 unit as MASTER, UART on VCOM):**

| Step | Pass | Result |
|---|---|---|
| OLED | splash, then ROLE | **Pass.** ACKs at 0x3C on P0.25/P0.26 at 400 kHz; no fallback needed. Needed the concat-buffer fix above. |
| SD | card mounts, count + free shown | **Pass** with the fab-data pins (SCK P1.14 / MISO P1.15), 4 MHz. The swapped mapping fails `CMD0`. |
| DET | raw level with / without a card | **Pass, active-low.** Raw 0 seated, raw 1 out, over two pull/reinsert cycles. |
| Logging | a soak writes a complete file | **Pass.** `P0_5M_000`: 744 records, 0 dropped. `P0_5M_001`: 2,001 records, 0 dropped. 0 write errors. |
| Radio | 5 min two-unit soak at +0 dBm: `slot=20000us` both cards, lock in single-digit seconds, PER 0.000 %, 0 missed / 0 dup, `dtx` ≈ 8292 µs | **Pass, with three units** (2026-09-25, below). |

Two bench lessons:

- **Early `CMD0` failures were an unseated card.** The push-push socket
  makes no contact until it clicks. DET reads raw 1 until then, so check
  DET before touching the SD pins.
- **Swapping the card while mounted breaks logging until reboot.** DET is
  read by the app only; the SD stack never re-initialises the card, so every
  write fails with -5. A remount on a DET change (unmount,
  `DISK_IOCTL_CTRL_DEINIT`, mount) would fix it; it is not built.

### First three-unit soak (2026-09-25)

The first run with more than two units: 5 min at +0 dBm and 20 ms slots,
all three logged to SD, using the unit pick above.
- **MASTER** (slot 0) and **SEC 1** were the two TFT consoles.
- **SEC 2** was the rev 2 field unit, since its log is that card's third
  file.
- All three files carry `META slot=20000us` and the right role and slot.

| Signal | Bar | MASTER | SEC 1 | SEC 2 |
|---|---|---|---|---|
| Lock | single-digit seconds | — | 1.35 s | 2.79 s |
| RX from each peer | PER 0.000 %, 0 missed/dup | slot 1: 3,734 · slot 2: 3,715, both **0 / 0** | 0 / 0 outside a log hole (below) | slot 0: 3,719 · slot 1: 3,715, both **0 / 0** |
| `evt_dt` median | 8292 ± tens of µs | 8,278 (8,221–8,328) | 8,299 (8,238–8,335) | 8,305 (8,248–8,343) |
| `phase_err` p95 / worst | ≤ 50 / < 125 µs | — | 35 / 52 µs | 33 / 51 µs |
| Frame spacing | 80 ms | 80,000 ± 14–22 µs | 80,000 ± 14–20 µs | 80,000 ± 19–21 µs |
| `stale_retx` / `slot_timeouts` / `busy` / CRC | all 0 | all 0 | all 0 | all 0 |

`ppm` means were +12.9 and −22.7, with σ 245–252. That matches the
acceptance soak and card #24's phase-jitter reading.

- **SEC 1's log has the 8 KB hole: a third occurrence.** Records
  2168–2295 are file sectors 271–286: 128 records, 16 sectors,
  sector-aligned, 40 zeroed and 88 stale. That is the same size and the
  same zeroed/stale mix as the acceptance-soak hole. A naive decode reads
  PER 1.1 % (83 "missed"). Both counter gaps (42 frames from slot 0, 41
  from slot 2) span exactly the hole, and the master received all 3,734 of
  SEC 1's transmissions. The 8 packets "from slot 1" in that file are
  stale records inside the hole; a slot-1 unit cannot receive slot 1. See
  Known limitations and card #25.
- **Card #23 is visible, in the form it predicts for syncing.** The first
  packet each secondary sends after lock arrives garbled at every receiver:
  frame counter 5, payload bytes 0/2/3 = `0xA1 · 0x05 0x00`, a received
  header's bytes. Everything after it is clean. Identical damage at every
  receiver puts it in the transmitter's buffer before it sends. That fits
  the receive pointer wrapping onto the staged TX payload while a secondary
  only listens during SYNCING. The master never syncs and is unaffected.
  With three units, each unit hears two packets per frame, so the
  steady-state wrap #23 predicts for four units did not occur.

### Intercom TDMA radio layer (M0-M2 implementation)

New product hosted in this tree: the L1/L2 radio layer for the sports-officials
intercom — a fixed 4-slot TDMA broadcast flood over the same SX1262 PHY
(915.0 MHz, SF5 / BW 500 kHz / CR 4-5, 44-byte fixed packets, 12-symbol
preamble, +22 dBm). Slot width 20 ms (one constant,
`TDMA_SLOT_DURATION_US`); frame = 4 slots = 80 ms. Bring-up ran at 50 ms;
the flip landed 2026-08-17, and its 30-minute two-unit acceptance soak passed
on 2026-08-18 (see "Slot width 50 ms → 20 ms" below).

- **L1** [`src/tdma/sx126x_cmd.c`](src/tdma/sx126x_cmd.c) — app-owned raw
  SX1262 opcode layer (datasheet-cited) with all BUSY gating in one choke
  point. The native Zephyr driver (L0) is used for init only; its DIO1
  callback (which did SPI on the system workqueue) is detached after
  `lora_config()` and replaced with the TDMA port's own
  (findings: [`docs/tdma_layering.md`](docs/tdma_layering.md)).
- **L2** [`src/tdma/`](src/tdma) — single radio thread (sole runtime SPI
  owner) polling slot-tick + DIO1 semaphores; hardware TIMER2 on HFXO
  (explicit `clock_control_on()` request, see hardware test findings below)
  via the counter API at 1 MHz with an accumulating absolute alarm target;
  RX slots run the chip in continuous RX, the slot boundary itself is the
  window's end; TX staging during RX-slot slack; drop-oldest RX msgq;
  telemetry counters. Secondary units acquire the master's slot-0 beacon
  (snap, then proportional step clamped to ±500 µs/frame) and go SYNCING →
  RUNNING after 3 beacons under 250 µs error. That transition is one-way:
  `tdma_start()` is the only entry into SYNCING, so a locked unit never
  re-enters acquisition and the lock threshold governs start-up alignment
  only.
- **App** (the UART-shell test variant, retired 2026-09-25) — Kconfig
  role/slot (`TDMA_ROLE_MASTER`/`TDMA_ROLE_SECONDARY`,
  `TDMA_SLOT_ID`), telemetry print every 5 s over UART, and `tdma` shell
  commands (`tx`, `rx [s]`, `start`, `stop`, `stats`) for M0 manual bring-up.
- Build: `west build -b nrf5340dk/nrf5340/cpuapp -p always -- -DCONFIG_APP_TDMA_TEST=y`
  (+ `-DCONFIG_TDMA_ROLE_SECONDARY=y` for the second unit).

### TDMA field console (2026-07-21)

First "test container": the bench diagnostics sequence above, packaged as an
on-device TFT applet for field soak testing —
[`src/tdma_console/main.c`](src/tdma_console/main.c). Reuses the telemetry
console's display toolkit ([`src/tdma_console/ui_widgets.c`](src/tdma_console/ui_widgets.c))
and touch calibration ([`src/tdma_console/touch_cal.c`](src/tdma_console/touch_cal.c));
the radio path is
exclusively the TDMA L1/L2 shim (the old console's native-driver modules —
`radio_cfg`/`payload`/`pingpong` — are not used). Display-only: no UART,
logging, or shell.

- **One image for both units**: role (MASTER/SECONDARY) is chosen at boot and
  locks at the first soak start (`tdma_init()` is once-only); reboot to
  change. Defaults to SECONDARY — two unconfigured units just listen instead
  of both beaconing into slot 0. (Role selection moved off HOME into the
  power-on sequence on 2026-07-31; see that section below.)
- **SOAK TEST** — pick 5 min / 30 min / 2 h / continuous; the engine runs the
  full TX/RX frame exchange while the screen shows live per-soak deltas:
  tx/stale, rx/crc/bad-hdr, phase error and ppm, RSSI/SNR, BUSY faults, and
  elapsed/limit. STOP (or the elapsed limit) parks the engine and freezes the
  stats until BACK; BACK alone never kills a running soak.
- **Frame-continuity loss stats**: the peer's `frame_ctr` advances once per
  frame, so per-slot counter gaps are missed frames and repeats are stale
  retransmits (`miss` / `dup` on the soak screen) — content-level loss the
  CRC counters cannot see, and the number that matters when evaluating
  tighter slot widths in the field.
- **TX power adjustable** (−9…+22 dBm, keypad entry): the one PHY parameter
  exposed in the UI. New engine API `tdma_set_tx_power()` latches the value
  from any thread; the radio thread issues `SetTxParams` right before the
  next `SetTx` (chip in FS — the datasheet-legal window), so it applies from
  the next packet without disturbing slot timing. Everything else stays a
  compile-time constant in [`src/tdma/tdma.h`](src/tdma/tdma.h).
- **TOUCH CAL** — the console's 5-point calibrate/verify flow (made a
  mandatory power-on step on 2026-07-31; see that section below).
- The soak screen is laid out for a future slot-width selector (the engine
  still pins `TDMA_SLOT_DURATION_US` at compile time; making it runtime is
  the planned next engine change for width evaluation).
- Build:
  `west build -b nrf5340dk/nrf5340/cpuapp -p always -d build-tft --`
  `-DEXTRA_DTC_OVERLAY_FILE=boards/nrf5340dk_nrf5340_cpuapp_tft.overlay`
  `-DEXTRA_CONF_FILE=boards/nrf5340dk_nrf5340_cpuapp_tft.conf`
  (the pair was `display.overlay` + `tdma_console.conf` until 2026-09-25;
  the SD stack was added to this build on 2026-07-31).

### Soak test harness (2026-07-30)

_Retired 2026-09-25 with the streamline to two unit types (see that entry above); kept as history._

New [`src/soak/`](src/soak) subtree (`CONFIG_APP_SOAK`): individually flashable
bench soak tests that stream machine-ingestible CSV over the DK's VCOM UART,
for quick automated ingestion of bench-top radio performance. Reuses the
[`src/tdma/`](src/tdma) L1/L2 engine unchanged — that layer has no dependency
on the application Kconfig symbols, only on the `TDMA_*` constants and the
`tdma_config` it is handed.

- **Role from a jumper, not a build flag.** P1.10 → 3V3 = MASTER (slot 0),
  open = SECONDARY (slot 1), via an internal pull-down
  ([`src/soak/role_select.overlay`](src/soak/role_select.overlay)). One image
  flashes to both units. P1.10 is free (the Wio-SX1262 shield uses only
  P1.00–P1.09) and sits on the port-1 header clear of the Arduino shield.
  Fails safe to SECONDARY if the GPIO cannot be read, so a unit never claims
  the timing-master role by accident.
- **Shared runner** [`src/soak/soak_run.c`](src/soak/soak_run.c) — brings up
  the engine at the requested TX power on the locked PHY, runs a fixed-length
  exchange, emits `SOAK,<id>,...` lines (meta / hdr / row / done / END) and a
  derived packet-error rate. The `SOAK,` prefix survives interleaved Zephyr
  log output.
- **First test** [`src/soak/s01_baseline_m9dbm_5min/`](src/soak/s01_baseline_m9dbm_5min)
  — both radios at −9 dBm (the SX1262 PA minimum, giving later tests a
  worst-case floor), 5 minutes, 5 s sample cadence. Each test owns a `main()`
  guarded by its own `CONFIG_SOAK_TEST_*` symbol, so only the selected one
  links; CMake globs `src/soak/**/*.c`, so adding a test needs no build-file
  edit.
- **Ingest** [`src/soak/tools/ingest_soak.py`](src/soak/tools/ingest_soak.py)
  — parses a saved capture or reads the serial port live, writes tidy CSV,
  prints the run metadata and summary.
- Build:
  `west build -b nrf5340dk/nrf5340/cpuapp -p always -d build-soak-s01 --`
  `-DEXTRA_CONF_FILE=src/soak/s01_baseline_m9dbm_5min/s01.conf`
  `-DEXTRA_DTC_OVERLAY_FILE=src/soak/role_select.overlay`

### Soak logging to SD (2026-07-31)

Every soak on the field console now writes a binary record log to the microSD
card — [`src/tdma_console/soak_log.c`](src/tdma_console/soak_log.c) over
[`src/tdma_console/sd_log.c`](src/tdma_console/sd_log.c). Automatic: it hangs
off `soak_start()` / `soak_finish()`, the only ways in and out of a run, so no
soak goes unlogged. Each run opens the next free `/SD:/SOAKnnn.BIN`.

- **Fixed 64-byte binary records, not CSV.** The payload alone is 40 bytes,
  which as hex text is 80 characters before any telemetry, and formatting it
  per packet costs far more than a `memcpy`. 64 B also divides 512 exactly, so
  eight records fill a FAT sector with nothing wasted and no partial-sector
  rewrite. `BUILD_ASSERT`s pin both the size and the division. Text formatting
  happens offline in the decoder, where it is free.
- **Rate budget** — sized for the 20 ms production slot, which is now the
  build's actual width: a 4-unit 80 ms frame yields 3 RX + 1 TX = 50
  records/s = 3.2 KB/s = ~6 sector writes/s. On the 2-unit bench it is half
  that.
- **Producers never touch the card.** Records go into a 128-deep `k_msgq`
  ring; a dedicated preemptible writer thread drains it. Mount, open, write
  and close all happen there, so a card stall blocks only the writer — never
  the UI loop, and never the cooperative radio thread that outranks both.
  Every FatFs call being on one thread also makes the LFN BSS working buffer
  (documented as not thread-safe) safe by construction.
- **Logging failure is non-fatal** — a missing or unreadable card must not
  abort a radio test. The soak runs regardless and the soak screen shows
  `LOG FAIL <stage> <errno>`, where stage is `disk` (card never came up),
  `mount` (volume rejected) or `open` (file creation failed).
- **What is captured**: full payload per received packet plus `t_us` (DIO1
  edge, for jitter), `frame_ctr`, RSSI/SNR and sync state; one record per
  *transmitted* packet; and a 1 Hz engine-counter snapshot plus a baseline
  snapshot at t=0. Record 0 is a META record describing role, PHY, TX power
  and slot/frame timing, so a decoded file is self-contained.
- **`tdma_rx_msgq` deepened 8 → 32** (`TDMA_RX_MSGQ_DEPTH` in
  [`src/tdma/tdma.h`](src/tdma/tdma.h)). Depth must cover the consumer's worst
  stall, not the average rate: at 50 records/s a couple of hundred ms of
  consumer stall silently dropped packets *before* any logger could see them.
- **Decoder** [`src/tdma_console/tools/decode_soak_log.py`](src/tdma_console/tools/decode_soak_log.py)
  — binary to tidy CSV plus a summary (RSSI/SNR spread, frame continuity,
  PER, engine counters). Detects on-device ring drops from `seq` gaps. Payload
  integrity is checked against the firmware's `payload[i] = base + i` pattern,
  recovering `base` by majority vote across all 40 positions rather than
  trusting `payload[0]` — one corrupted first byte would otherwise make every
  byte look wrong.

> [!NOTE]
> Because packet CRC is on, the modem drops corrupted frames and they never
> reach the log, so payload checking reads clean essentially always. Measuring
> true BER would mean disabling the packet CRC so damaged frames still surface.

### First logged soak + log format v2 (2026-08-01)

First 5-minute two-unit soak captured to SD and decoded off the cards, at
−9 dBm on the 50 ms bench slot. The record format, writer and decoder were
validated end to end on the first attempt — no padding or byte-order
mismatch — and **neither file had a single `seq` discontinuity**, so the ring
dropped nothing at ~1.16 KB/s.

- **Zero packet loss in both directions**: 1486 frames in which both units
  logged a packet, 0 missed / 0 dup / 0 payload bit errors either way, one
  CRC error total. RSSI −67…−62 dBm, SNR 6…10 dB. The secondary's three
  "extra" frames (counters 2–4) are simply the master starting its soak three
  frames later, not loss — both files end on counter 1490.
- **Slot timing has enormous margin at the 20 ms target.** RX inter-arrival
  error against the nominal frame: σ = 21 µs, p50 ≈ 0, p99 +55 µs, full range
  −135…+69 µs; the secondary's sync phase error held to −63…+36 µs. A 20 ms
  slot leaves 12.37 ms of guard after the 7.632 ms time-on-air, so the worst
  observed excursion is ~1 % of the budget. Clock discipline is not what
  limits tightening the slot.
- Caveat: ~45 dB of margin over SF5/BW500 sensitivity on the bench. 0 % PER
  here says the stack is correct; it says nothing about range.

Three logging defects the first real capture exposed, all now fixed:

- **TX records counted submissions, not transmissions.** The master logged
  3693 TX records against 1499 actual transmissions — `tdma_tx_submit()`
  succeeds whenever the engine's stage buffer is free, which the 20 ms UI loop
  hits ~2.4× per frame, and every extra payload was overwritten in place
  before its slot. Two thirds of the file described bytes that never reached
  the air. The runner now holds a payload "armed" and logs it only once the
  engine's `tx_done` confirms it went out, so a TX record is a transmission
  and carries the payload that was actually sent.
- **`ppm` was destroyed by clamping.** v1 squeezed the clock-rate estimate
  into the record's `int8` `snr` field, where it railed at ±127 — and that is
  the single measurement that matters most for tightening the slot. The phase
  error had the same latent bug (`int16` cannot hold the ±frame/2 range).
  Format **v2** gives STATS a typed 40-byte overlay (`struct soak_stats`) with
  both as `int32`, making room by dropping `rx_ok`/`missed`/`dup` — which the
  decoder derives from frame-counter continuity anyway.
- **Engine counters are absolute, not per-soak.** `tdma_start()` deliberately
  does not reset `eng.telem`, so a second soak in one boot keeps counting: the
  master's log read `tx_done=1608` absolute against 1499 for that run. A
  baseline STATS record is now written at t=0 and the decoder reports
  `engine (this run)` alongside `engine (absolute)`.

The decoder reads both v1 and v2, so the captures above remain readable; it
prints the format version and warns when a v1 log's `ppm` sits on the int8
rails.

### Log naming, drawers + SD file browser (2026-08-01)

Soak log names now encode the run: `<PWR>_<DUR>_NNN.BIN` — `M`/`P` for the
power sign and minutes/hours for the duration (`M9_5M_000.BIN`,
`P22_2H_007.BIN`, `CT` = continuous). Long-name support is always compiled in
(exFAT selects `FS_FATFS_LFN`, and LFN works on FAT32 too), so the old 8.3
constraint no longer applies. Logs can be pointed at one of four fixed
top-level drawers (`DRAWER0`–`3`) or the root, selected on the soak-pick
screen ("LOG" row); a missing drawer is created when a log opens there.

- **FILES browser** on HOME: list (directories first, 10 rows, DK-button or
  tap scroll), **delete** with a two-press confirm, **move** between root and
  drawers (`fs_rename`, destination auto-created), **+ DRAWER** (next free of
  the four), and an optional **label** appended before the extension
  (`M9_5M_000_RANGE1.BIN`) — never part of a default name.
- **Alpha keypad**: third key table for the existing modal (A–Z 0–9 `_`,
  6×7 grid; the grid's column count is now per-table). Used for labels.
- **All card I/O stays on the writer thread**: the browser submits one op at
  a time (`sd_fsop_*` in soak_log.c) and polls from the 20 ms loop — the LFN
  working buffer is a shared static (not thread-safe) and a sick card must
  never stall the UI, so this holds by construction, browser included.
- Foreign directories (e.g. Windows' "System Volume Information") list but
  are not enterable; >64 entries shows a truncation marker.

### TX-start latency instrumentation (2026-08-12)

Instrumentation to measure `TDMA_TX_START_LATENCY_US` on the bench — no
constant or behaviour change yet. The header defines the constant as the
chip-only SetTx→first-preamble latency (100 µs), but its one consumer,
`tdma_core_sync_feed()`, needs the full boundary→first-preamble delay, which
additionally contains the radio-thread wake and the `slot_tx_enter` SPI
sequence (ClearIrqStatus / SetFS / SetTx, each behind BUSY waits) — the
~1 ms gap. The plan is to redefine the constant as boundary→air and set it
from measurement rather than refine the chip figure.

- **Two telemetry fields** (additive; the STATS v2 SD overlay is at exactly
  40 bytes and is deliberately untouched): `dt_by_slot[]` — `last_evt_dt_us`
  attributed to the slot it occurred in — and `tx_evt_dt_us`, that dt latched
  only on TxDone events, i.e. this unit's own boundary→TxDone delay
  (TX latency + time-on-air), independent of sync alignment.
- **Soak screen gains a `dtx N  drx N` row**: own TX dt plus the watched peer
  slot's RX dt (2-unit kit: master watches slot 1, secondary slot 0).
- **Why both**: the open "~1.1 ms per-role asymmetry" (07-21 findings, below)
  may not be per-role at all — `slot_tx_enter` has no role branch. A locked
  secondary aligns its boundary through the wrong constant and so sits late
  by exactly the constant's error, which makes *cross-unit*
  boundary-referenced readings differ by ~1.1 ms even if the two units' true
  TX latencies are identical. Own `dtx` is immune to that offset; cross-slot
  `drx` carries it. Comparing the two separates a real asymmetry (split
  per-role constants) from a plain constant error (one corrected constant).
- Built-in self-check: the secondary's `drx` should read ≈7732 µs
  (TOA_const + L_const) regardless of the true latency — the sync loop
  aligns it there by construction. If it doesn't, the instrumentation itself
  is suspect.
- These fields join the bench-diagnostics strip candidates (see
  "Bench diagnostics" below), except `tx_evt_dt_us` is likely worth keeping
  as the permanent regression check on the constant.

### TX-start latency measured; TOA + latency constants corrected (2026-08-16)

Bench measurement over the instrumentation above (both consoles, 50 ms
slots) closed the question: **there is no per-role asymmetry**. Both units
read boundary→TxDone `dtx` = 8292 µs — identical — and every self-check
landed exactly: the secondary's `drx` held at 7732 µs (TOA_const + L_const,
where the sync loop parks it by construction) and the master's
`drx` = 8852 µs matched the predicted sync offset Δ = 560 µs to the
microsecond.

The "~1.1 ms per-role asymmetry" from the 07-21 findings is thereby
resolved as a **constant error propagated through sync alignment**: the
secondary aligned its boundary through the wrong constants and sat 560 µs
late (432 µs latency error + 128 µs TOA error), which any cross-unit
boundary-referenced reading picked up in full — while the TX paths
themselves are exactly role-symmetric.

Two constants corrected in [`src/tdma/tdma.h`](src/tdma/tdma.h); no code
change:

- **`TDMA_TOA_US` 7632 → 7760.** The derivation used SF7+'s 4.25-symbol
  preamble sync overhead; SF5/SF6 carry 6.25 symbols, so
  t_preamble = (12 + 6.25) × 64 = 1168 µs.
- **`TDMA_TX_START_LATENCY_US` 100 → 532**, redefined from the chip-only
  SetTx→air figure to the full boundary→air delay its one consumer — the
  sync equation — actually needs: radio-thread wake + the `slot_tx_enter`
  SPI sequence + chip latency. 532 = measured 8292 − TOA 7760.
  `tx_evt_dt_us` reading TOA + this constant is the standing regression
  check.

Effect: a locked secondary's boundary moves 560 µs earlier, coinciding with
the master's. Guard budget at the 20 ms target: worst in-slot completion is
532 + 7760 ≈ 8.3 ms, leaving ~11.7 ms of slack — now a measured number
rather than an estimate. Confirmed on the bench after reflashing both
units: all four soak-screen readings (`dtx`/`drx`, both roles) collapsed
to ≈8292 µs with tens-of-µs jitter, i.e. the sync offset Δ went to zero
as predicted.

### Payload staging moved off the UI loop (2026-08-19)

First bench run at 20 ms exposed an application-layer regression the flip
caused but did not itself contain: the master reported `stale_retx` = 79
against 224 transmissions — **35 % of packets re-sending the previous
payload** — growing linearly from the first second. The 50 ms baseline was
48 in 30 minutes. Confirmed independently from the air: 30.4 % of
consecutive RX packets carried an identical payload base, i.e. both units
were doing it.

**The engine was never at risk, and that distinction is the point.** Through
the whole 35 % run `dtx` held 8249–8300 µs and `slot_timeouts` stayed 0 —
the radio thread is cooperative at `K_PRIO_COOP(4)` and preempts the UI, so
slot timing was untouched. What starved was the *application data path*,
which shared a thread with the screen.

**The budget the flip actually cut.** The engine takes a staged payload in
`rx_slot_slack_work()`, which runs at every RX-slot entry, so the last
chance before a unit's next TX comes `TDMA_SLOT_COUNT - 1` slots after its
own. The window runs from TxDone to that entry:

    (SLOT_COUNT - 1) × SLOT_DURATION - (TX_START_LATENCY + TOA)

141.7 ms at 50 ms slots, **51.7 ms at 20 ms** — a 63 % cut, and
role-symmetric. `draw_soak_dynamic()` clears the body with a full-width SPI
fill before drawing its rows and overruns 51.7 ms on its own, so every
repaint dropped a frame's payload: 4 repaints/s against 4.4 stale/s. The
same cost fitted inside the 50 ms budget, which is why it only surfaced
after the flip.

Fix, in [`src/tdma_console/main.c`](src/tdma_console/main.c):

- **New `soak_data_tid` at `K_PRIO_COOP(6)`** — below the radio thread,
  above every preemptible thread. It owns the RX drain, the TX arm/re-stage
  and the periodic STATS snapshot, ticking at 2 ms. It never touches SPI and
  never blocks, so sitting above the UI costs the UI nothing. The UI loop
  keeps drawing, input, and the teardown only: `soak_finish()` closes the log,
  which waits on the card writer for up to 5 s and must not run on a
  cooperative thread. The data thread therefore latches `soak.expired` and
  the UI performs the stop.
- **A headroom gauge on the soak screen**, `lat N/51ms`, since the question
  is ongoing rather than one-off: worst pass-to-pass latency of the data
  thread against the budget. Under budget, staging cannot be late and
  `stale_retx` is impossible; it degrades visibly long before any packet
  does, which is what makes it useful as the product takes on more concurrent
  work.
- Cost: +448 B flash, +1712 B RAM.

> [!NOTE]
> The gauge first shipped measuring the interval between successful
> `tdma_tx_submit()` calls, which is wrong: a submit can only follow the
> previous *transmission* (the `tx_armed` gate that makes the log record
> transmissions rather than submissions), so that interval has a floor of one
> frame period — 80 ms — and cannot be compared with a within-frame deadline.
> It read 88 ms on a healthy master (80 ms frame + 8 ms) and 349 ms on a
> secondary (acquisition: it locked at +0.676 s and cannot transmit before
> RUNNING). Both were correct behaviour reported as failures. The budget
> constrains how long after TxDone the application takes to re-stage, which is
> bounded by how promptly the data thread runs — hence pass-to-pass latency.

**Result** — 20 ms, +0 dBm, two units, ~29 s, secondary logged to SD:
`stale_retx` **0 across 353 transmissions**, flat from the first second.

### Slot width 50 ms → 20 ms (2026-08-17)

`TDMA_SLOT_DURATION_US` 50000 → 20000 in [`src/tdma/tdma.h`](src/tdma/tdma.h)
— step 4, the last step of the tightening sequence. Frame follows to 80 ms
and `TDMA_SLOT_ACTIVE_US` to 18 ms, both derived. A straight constant flip:
no runtime slot-width selector, which stays a separate card.

**Acceptance soak: passed** (Trello card #6, 2026-08-18). The run was
30 min, both bench units at +0 dBm, SD-logged on both sides (master
`P0_30M_000.BIN`, secondary `s_P0_30M_000.BIN`, both `META slot=20000us`).
The logs are not kept in the repo; the figures below were decoded from them.
It ran with the payload-staging fix below, which is committed as `3746f11`
at 01:05 on 2026-08-19, so the session evidently ran past midnight. The
proof is `stale_retx`, which is 0 throughout. Results against the pass
criteria at the end of this entry, from the secondary's log unless noted
(STATS once a second, 1740 samples after the first minute):

| Signal | Bar | Measured |
|---|---|---|
| Lock | single-digit seconds | **1.66 s** |
| `dtx` / `drx` | 8292 ± tens of µs, same value both roles | `evt_dt` median **8292** (8231–8355) secondary, **8288** master |
| `phase_err` | median ≈ 0, p95 \|err\| ≤ 50 µs, worst < 125 µs | **+1 / 38 / 75 µs**, σ 17; no drift (half-run means +0.06 / +0.07) |
| Link, master → secondary | PER 0.000 %, 0 missed/dup, 0 `seq` gaps | **22,483 received, 0 missed / 0 dup, 0 `seq` gaps** |
| Link, secondary → master | same | master `rx_done` **22,480** = secondary `tx_done` 22,480; log: see below |
| Counters | `stale_retx`, `busy_timeouts`, `slot_timeouts` all 0 | **all 0, both units** (22,500 / 22,480 transmissions) |
| Frame spacing | 80 ms | RX timestamps 80,000 ± 23 µs (σ), both units |
| `ppm` | mean within a few ppm of −6.9 | mean −1.7, standard error ≈ 6, so consistent; σ 265, see below |

`rx_crc_err` totalled 1 (master) + 3 (secondary). Two things stand out:

- **The master's log has a hole: the known one, again.** Records
  29,344–29,472 start on a sector boundary and hold 112 zeroed records plus
  stale sectors from an earlier run. Decoded naively, the master's file
  reads PER 26 % (7,889 "missed"), because `frame_ctr` jumps into the stale
  data and back. Outside the hole, `seq` and `frame_ctr` are continuous, and
  the engine counters above show the link lost nothing. This is the second
  occurrence of the 8 KB hole under Known limitations, now at 20 ms, and is
  tracked as card #25.
- **`ppm` σ is 265, not the ~170 predicted.** It matches the 304 seen in
  the short runs below, so the spread is real, not noise. Card #24 has the
  explanation: at this frame rate the per-beacon figure is phase jitter
  ×12.5, not a rate estimate. The mean is still the signal.

The short bench runs at 20 ms that preceded the soak (~29 s, +0 dBm, two
units, secondary logged to SD; sample counts in parentheses) had cleared
every criterion they were long enough to test:

| Signal | Bar | Measured |
|---|---|---|
| Width on air | 80 ms frames | 12.46 frames/s ✓ |
| `dtx` | 8292 ± tens of µs | median **8292**, 8250–8318 (29) |
| `phase_err` | median ≈ 0, p95 ≤ 50 µs, worst < 125 µs | **+1 / 38 / 38 µs** (29) |
| Lock | single-digit seconds | **0.68 s** |
| Link | PER 0 %, 0 missed/dup, 0 `seq` gaps | all clean (326 pkts) |
| Counters | `stale_retx`/`slot_timeouts`/`busy_timeouts` = 0 | all 0 |
| `ppm` | mean within a few ppm of −6.9 | **inconclusive** — see below |

`dtx` landing on 8292 is the standing regression check on the corrected
`TDMA_TOA_US` 7760 and `TDMA_TX_START_LATENCY_US` 532: it holds at the new
width. The phase envelope (−33…+38 µs) is *tighter* than either 50 ms
baseline, the direction the 2.5× beacon rate predicted.

Two reasons those runs could not stand in for the acceptance soak:

- **29 samples over 29 s**, against 575 over 11 min for the 50 ms baseline.
  A short run sees a narrower envelope purely from fewer draws, so the phase
  figures will widen in a real soak. They pass with room; that is not proof.
- **`ppm` cannot be tested at this length.** Mean +32.3, median −18, σ 304
  over 24 samples puts the standard error near 62 ppm — consistent with the
  true −6.9 and with much else besides. Worth noting σ came in at 304 against
  the ~170 predicted for 80 ms frames; with 24 samples that is likely real
  rather than noise, so it is a thing to watch in the 30-minute run rather
  than a settled figure.

Pre-flight audit, all clear at head:

- Every variant's `tdma_config.slot_duration_us` passes the macro, never a
  literal — [`soak_run.c`](src/soak/soak_run.c),
  [`tdma_app/main.c`](src/tdma_app/main.c),
  [`tdma_console/main.c`](src/tdma_console/main.c) — and `tdma_init()`
  rejects a mismatch, so a stale literal would fail loudly rather than run
  a split-brain frame.
- Worst in-slot completion is `TDMA_TX_START_LATENCY_US` + `TDMA_TOA_US` =
  8292 µs against an 18 ms `SLOT_ACTIVE`, ~9.7 ms of headroom. That governs
  the TX timeout only; RX is continuous, so the slot boundary itself ends
  the window.
- `TDMA_SYNC_STEP_CLAMP_US` stays 500 µs, now per 80 ms frame — max slew
  rises 2.5 → 6.25 ms/s. Intended: beacons arrive 2.5× more often, so the
  loop should correct 2.5× faster.
- `TDMA_RX_MSGQ_DEPTH` 32 was already sized for the 20 ms 4-unit case.
- The HFXO request in [`tdma_port.c`](src/tdma/tdma_port.c) becomes
  load-bearing rather than prudent: the ~−1000 ppm of RC drift it avoids is
  absorbable at 50 ms, not at 20 ms. Comment updated to say so.

**Pass criteria for the acceptance soak** (30 min, both bench units, +0 dBm,
SD-logged both sides; 50 ms baselines in parentheses):

| Signal | Bar | Baseline |
|---|---|---|
| Lock | SYNCING → RUNNING in single-digit seconds | 2.30 s |
| `dtx` | 8292 ± tens of µs, both roles | 8292 |
| `drx` | collapses to the same value both roles | 8290 / 8291 |
| `phase_err` | median ≈ 0, p95 \|err\| ≤ 50 µs, worst < 125 µs | 0 / 24 / 51 |
| Link | PER 0.000%, 0 missed/dup, 0 `seq` gaps | same |
| Counters | `stale_retx`, `busy_timeouts`, `slot_timeouts` all 0 | same |
| `ppm` | mean within a few ppm of −6.9 | −6.9 |

Two readings that would be misread as regressions: per-sample `ppm` σ should
*grow* to ~170 (the estimator divides the same ±13 µs timestamp jitter by an
80 ms frame instead of 200 ms — the mean is the signal), and `phase_err`
growth toward the 250 µs bar is a red flag even if the unit locks, since
2.5× more frequent beacons should make the envelope equal or tighter.

**Soak duration constraint at 20 ms**: `frame_ctr` wraps at 1.46 h (see
Known limitations). Runs needing cross-file pairing must stay under that;
the console's 2-hour preset exceeds it.

### Sync lock threshold tightened to 250 µs (2026-08-16)

`TDMA_SYNC_LOCK_ERR_US` 1000 → 250 in [`src/tdma/tdma.h`](src/tdma/tdma.h).
Step 3 (second half) of the 50 ms → 20 ms tightening sequence, taken after
the accumulate change below soaked clean.

**What the constant actually governs.** Acquisition only. It is the bar
`SYNCING` measures against to reach `RUNNING`, and there is no
`RUNNING` → `SYNCING` path — `tdma_start()` is the sole entry into
`SYNCING`, so once a unit locks it stays locked and a beacon over the
threshold only resets `lock_streak`. Tightening therefore cannot destabilise
a running link; it raises how well aligned a unit must be before it starts
transmitting, at the cost of possibly sitting in `SYNCING` a little longer.

**Measured basis** — 11 min two-unit soak, 50 ms slots, +0 dBm, both roles
logged to SD (fmt v2):

- Secondary steady state (575 samples after 60 s): `phase_err` median 0 µs,
  mean −1.7 µs, p95 |err| 24 µs, envelope −51…+27 µs. No drift — first-half
  mean −1.85 µs vs second-half −1.61 µs.
- Worst |`phase_err`| anywhere in the run was 51 µs, so 250 µs keeps ~5×
  margin over the observed envelope.
- Acquisition was already inside ±11 µs before the first lock (`SYNCING` →
  `RUNNING` at +2.30 s), so the tighter bar would not have delayed this
  run's lock at all.
- `drx` median 8290 µs (secondary) / 8291 µs (master), σ 13–15 µs — both
  roles agreeing to 1 µs, as the constants correction above predicted.
- Link: PER 0.000%, 0 missed, 0 dup over 3322 packets; `slot_timeouts`,
  `stale_retx`, `busy_timeouts` all 0 on the secondary.
- `ppm` is a real reading for the first time (v1 railed it at ±127): mean
  −6.9 ppm crystal-to-crystal offset. Its σ of 68 is measurement noise, not
  clock instability — a per-beacon estimate over one 200 ms frame turns the
  observed ±13 µs timestamp jitter into ±65 ppm.

### Phase corrections accumulate (2026-08-16)

`tdma_port_add_phase_adj()` in
[`src/tdma/tdma_port.c`](src/tdma/tdma_port.c) was named "add" but
implemented *set* (`atomic_set`), so a second post landing before the next
slot boundary silently discarded the first. Now `atomic_add`: corrections
accumulate into one pending value that `slot_alarm_cb()` folds in once via
`atomic_clear`.

No behavior change for today's call pattern — `tdma_core_sync_feed()` posts
one correction per beacon (one per frame) and boundaries consume four times
per frame, so there is never more than one outstanding value. It matters
once two posts can land between consumptions: a slew-limited loop splitting
a large error into partial steps, or a drift/ppm feed-forward writer
alongside the beacon correction, both on the table for the M3 filter work.
A dropped ms-scale correction leaves the boundary transiently misaligned
until the next beacon pulls it back — at 20 ms slots that is a meaningful
fraction of the guard budget, though it cannot change sync state (nothing
leaves RUNNING once locked).

- The race with the consumer is benign under add: a post either lands
  before the ISR's `atomic_clear` (applied at that boundary) or after
  (pending for the next). Nothing is lost.
- Negative adjustments still work through two's-complement wraparound on
  the unsigned add at the consumer; the `(uint32_t)` cast stays.
- **No consumption-side per-boundary clamp.** Post-side clamping already
  exists where it matters (steady-state step clamped to
  ±`TDMA_SYNC_STEP_CLAMP_US` at the call site), and the acquisition snap is
  deliberately unclamped and forward-only. A per-boundary application clamp
  belongs with the M3 sync-filter rework (`TODO(M3+)` in
  `tdma_core_sync_feed()`).

Step 3 (first half) of the 50 ms → 20 ms tightening sequence; tightening
`TDMA_SYNC_LOCK_ERR_US` to ~250 µs follows as a separate change once this
soaks clean. Task write-up:
[`docs/phase_adj_accumulate.md`](docs/phase_adj_accumulate.md).

### Mandatory power-on sequence + minimal HOME (2026-07-31)

The field console now runs a two-step, session-only power-on sequence before
HOME is reachable: **TOUCH CAL → SELECT ROLE**. Neither is reachable from HOME
afterwards — reboot to redo either.

- **Calibration first, deliberately**: the transform is RAM-only, so every
  boot starts from the identity mapping and the role could not otherwise be
  picked by touch. Point collection uses the *raw* samples, so it bootstraps
  correctly from the identity transform.
- **ACCEPT / REDO touch buttons** on the verify screen, so confirming no
  longer needs a DK button. These exist only in the verify phase, and that is
  the point: it is the one phase where a freshly solved transform is already
  active, so a tap lands where it looks — tapping ACCEPT accurately *is* the
  proof the fit is good. In collect (identity transform) and fail (solve
  rejected) an on-screen button would be unpressable, so the DK buttons stay
  the only control there, and remain a working fallback throughout.
- **Calibration text no longer collides with the first target.** The
  instruction line sat at `MARG + body + 2` and ran straight through the
  top-left crosshair — the one target you look at while reading it. It now
  derives its baseline from the same 15 % inset `cal_target()` uses, so it
  clears every target and stays correct if the panel geometry changes.
- **SELECT ROLE** — two full-width touch buttons. The highlight starts on the
  current role (SECONDARY by default), so confirming without moving takes the
  fail-safe option instead of creating a second master.
- **HOME reduced to SOAK TEST + TX pwr.** Role and touch cal left the menu;
  role moved into the HOME header (`FIELD TEST: MASTER`), since with two
  identical DKs on the bench it is the one thing that cannot be inferred by
  looking at them.

### Hardware test findings (2026-07-31) — SD card bring-up

Found while bringing the soak logger up against a 128 GB exFAT card; the
smaller FAT32 card had masked all of it.

- **Root cause 1 — the logger could reformat the operator's card.**
  `CONFIG_FS_FATFS_MOUNT_MKFS` is enabled by default, and the mount struct
  left `.flags` at 0. Zephyr's answer to a `FR_NO_FILESYSTEM` mount is then
  `f_mkfs(FM_ANY | FM_SFD)` — which reformats the card and, with `FM_SFD`,
  writes no partition table at all. A card that had been in the unit came back
  to a PC as garbage, consistent with a partial run of exactly that. Fixed
  three ways: `FS_MOUNT_FLAG_NO_FORMAT` on the mount, `MOUNT_MKFS=n` to remove
  the code path, and both documented at the site.
- **Root cause 2 — card I/O ran on the UI thread.** Mount, open and the
  session-file scan all happened inside `soak_start()`, and the scan only
  broke out of its 1000-candidate loop on `-ENOENT` — so a volume erroring
  every `fs_stat` produced a thousand SPI round-trips and a frozen UI. The
  scan now aborts on any non-`-ENOENT` error, and all card I/O moved to the
  writer thread. The UI can no longer be stalled by the card in any state.
  This also retired a ~1.5 s freeze on every soak start with no card inserted
  (`CONFIG_SD_INIT_TIMEOUT`).
- **Root cause 3 — the card never enumerated.** With the stage-aware error
  reporting added above, the failure reported `disk -134` (`ENOTSUP`) and
  `disk -116` (`ETIMEDOUT`) on successive attempts — meaning the filesystem
  was never reached, and exFAT support was never the issue. The *alternation*
  was the diagnostic: a genuinely unsupported card fails identically every
  time, so two different errors on identical attempts meant garbled responses,
  i.e. a physical-layer problem. Fixes, in the display overlay:
  `power-delay-ms` 1 → 250 (the binding's own note says to raise it when card
  init misbehaves; a large SDXC card draws far more inrush than the smaller
  one and the SD spec allows 250 ms before a card must answer), and
  `spi-max-frequency` 24 MHz → 4 MHz (the logger needs ~3.2 KB/s, so this
  keeps two orders of magnitude of headroom while being far kinder to a card
  on jumper wires sharing the display bus). `sd_log_mount()` also retries the
  bring-up three times, 250 ms apart. Verified writing reliably afterwards.
- **exFAT support added** for cards Windows will not format as FAT32:
  `CONFIG_FS_FATFS_EXFAT=y` (which auto-selects `FS_FATFS_LFN` — FatFs
  requires it) plus `CONFIG_FS_FATFS_LBA64=y` for GPT-partitioned cards.
  Filenames stay 8.3-clean so the same naming works on FAT32.

### Hardware test findings (2026-07-21) — link closed full-duplex

Supersedes the same-day entry below on two points (the "benign" timeout ratio
and the guard-lead fix): both were wrong, found by adding per-slot bench
diagnostics (next section) and reading the chip's actual state instead of
inferring it from DIO1 activity alone.

- **Root cause 1 — dead alternating RX windows.** The per-slot `SetRx`
  timeout left every other RX window non-functional: armed and confirmed in
  RX mode by `GetStatus`, but never raising a DIO1 edge. `arm/slot` vs
  `evt/slot` tallies made this unambiguous (e.g. `[119 119 119 118]` armed
  against `[21 118 1 117]` events), and the raw DIO1 edge counter matched the
  accounted events exactly, ruling out lost interrupts. This — not a "benign
  2:1 ratio" — was the earlier master-side timeout:TX anomaly and the root
  cause of the secondary's marginal (~1/min) beacon reception. Fix: RX slots
  now run the chip in continuous RX (`SX126X_RX_CONTINUOUS`); the slot
  boundary is already the window's end, so the chip's own timeout was
  redundant. `slot_timeouts` no longer fires for RX slots as a result.
- **Root cause 2 — HFCLK on the uncalibrated internal RC oscillator.**
  Nothing in this build requests HFXO (no BLE/802.15.4 stack does it
  implicitly), so TIMER2 — the slot clock — free-ran on the internal RC.
  Measured ~1000 ppm relative drift between the two units from consecutive
  beacon timestamps, ~25–40x a crystal's tolerance and enough on its own to
  keep the sync loop from converging. Fix: `tdma_port_init()` now issues an
  explicit `clock_control_on(clk, CLOCK_CONTROL_NRF_SUBSYS_HF)`, held for the
  engine's life. Dropped the secondary's steady-state `phase_err` from
  ~400 µs to single-digit µs and `ppm` to ~0.
- **Root cause 3 — the previous guard-lead fix was itself a bug.**
  `TDMA_RX_GUARD_LEAD_US` biased the *entire* frame 1.5 ms early, not just
  the secondary's RX window, so its own TX slot fired 1.5 ms before the
  master was listening and the master decoded none of it. This was masked
  until root cause 2 was fixed — the old, sloppy ~400 µs phase error
  happened to leave just enough of the 1040 µs preamble inside the master's
  window to pass by luck. Removed outright: continuous RX (root cause 1)
  makes a guard lead unnecessary.
- **Result**: full duplex on hardware, ~5 packets/s each direction, zero
  CRC/header errors either side, sync lock in ~6 s, `phase_err` settling to
  single-digit µs, RSSI −36…−40 dBm / SNR +7…+9 dB throughout.
- **Open items before tightening to 20 ms slots**: TX-start latency
  appeared to differ between master and secondary by ~1.1 ms — resolved
  2026-08-16 as a constant error propagated through sync alignment, not a
  per-role difference: measured role-identical, and both
  `TDMA_TX_START_LATENCY_US` and `TDMA_TOA_US` corrected (see "TX-start
  latency measured" above); `tdma_port_add_phase_adj()` overwrote rather
  than accumulated a pending correction (latent — only one correction is
  issued per beacon today) — resolved 2026-08-16, it now accumulates (see
  "Phase corrections accumulate" above). Both are now closed, and the
  tightening sequence completed 2026-08-17 with the slot flip itself
  (step 3: `TDMA_SYNC_LOCK_ERR_US` 1000 → 250 µs; step 4:
  `TDMA_SLOT_DURATION_US` 50 → 20 ms). What remains before calling 20 ms
  proven: the 2-unit acceptance soak at the new width, then a 4-unit soak
  (gated on building units 3 and 4), then the field campaign.

### Bench diagnostics (2026-07-21)

Added to `tdma_get_telemetry()` / printed by `tdma stats` and the 5 s
periodic print, to tell apart "receiver never armed" from "armed but heard
nothing" from "heard energy but never completed a packet" — the ambiguity
that made root causes 1–3 above hard to see from the pre-existing counters
alone:

- `rx_arm` / `arm_by_slot[]` — `SetRx` issuances, per slot.
- `dio1_edges` — raw DIO1 ISR edge count, to catch events dropped between the
  pin and the drain (none were; see root cause 1).
- `drain_empty` — drains that read `IrqStatus == 0`.
- `preamble_det` / `header_valid` — `PreambleDetected` / `HeaderValid`
  latched in `IrqStatus` but deliberately *not* routed to DIO1
  (`SetDioIrqParams` takes the enable mask and the pin routing separately),
  so a live receiver hearing energy can be told apart from a dead one even
  when no full packet ever completes.
- `rx_mode_bad` / `last_chip_mode` — post-`SetRx` `GetStatus` mode check.
- `last_ppm` — relative clock-rate estimate between local and master slot
  clocks from two consecutive beacon timestamps and the frame counter delta
  in the header, free of the ±frame/2 wrap that makes `last_phase_err_us`
  ambiguous over long gaps between beacons.
- `evt_by_slot[]` / `last_evt_dt_us` — per-slot event counts and
  boundary-to-event delay, isolating which slot a symptom is in.

Bring-up scaffolding, not part of the M2 design — strip once the link is
proven at the 20 ms production slot width.

### SDK setup fixes (Windows / NCS v3.2.0)

- New [`patches/0003-lora-h-native-driver-api-compat.patch`](patches/README.md):
  stock NCS v3.2.x ships an older `include/zephyr/drivers/lora.h` missing
  `SF_5`, the narrow `BW_*` members, `packet_crc_disable` and the
  `recv_duty_cycle_async`/`airtime` API — nothing in this repo compiled
  against it. The patch mirrors the newer upstream header the vendored driver
  was written against.
- `patches/apply.sh` now applies with `--ignore-whitespace` (CRLF checkouts on
  Windows put CRLF driver files into the SDK; the LF patches otherwise refuse
  to match) and globs all numbered patches.

### HOME menu

_Retired 2026-09-25 with the streamline to two unit types (see that entry above); kept as history._

The console boots to a HOME screen. Navigate with the DK buttons
(**B1 = UP, B2 = DOWN, B3 = OK, B4 = BACK**) or by touch. The footer shows the
live applied-config summary.

- **SEND ONCE** — Fire a single transmit. Snapshots the current PAYLOAD bytes and
  the APPLYed RF config, signals the background TX thread to call `lora_send()`,
  and switches to the **TX STATUS** sub-screen: a spinner while in flight, then
  the result (SENT/FAILED, driver return code, byte count, and the config used).
  Requires a prior successful APPLY and a non-empty payload.
- **PING PONG** — Symmetric two-radio link test (both units run identical
  firmware; there are no roles). Enters continuous RX on the applied config;
  **SEND PING** transmits a 44-byte ping and the peer echoes a pong with the same
  sequence number, so the originator can measure round-trip time. A **STATS**
  sub-screen shows sent/received/lost counts and RTT last/min/max/avg;
  **RESET STATS** clears them. Outstanding pings time out after 1 s. All state is
  shown on the STATS sub-screen (this build has no serial output).
- **CONFIG** — Stage-then-apply RF configuration. Rows for frequency, spreading
  factor, bandwidth, coding rate, TX power, preamble, CRC, IQ, and network sync
  edit an in-RAM _shadow_ `lora_modem_config`; a `*` in the header marks it dirty.
  **APPLY** validates the shadow (902–928 MHz, −9…+22 dBm, preamble ≥ 6 and ≥ 12
  for SF5/SF6) and commits it with a single `lora_config()` call. Enum/bool rows
  cycle in place; numeric rows open the keypad.
- **PAYLOAD** — TX payload editor. Displays the current bytes as hex with a length
  counter (up to 255 bytes). **EDIT** opens the hex keypad; **CLEAR** empties it;
  presets load `0x00…`, `0xFF…`, an incrementing ramp, or the ASCII test vector
  `BLUEFROG`.
- **TOUCH CAL** — Touchscreen calibration. Tap five on-screen crosshairs; the
  firmware least-squares-fits a 6-parameter affine transform (correcting the
  rotated / offset / swapped XPT2046 axes versus the display) and offers a verify
  step that shows where taps land. The fit is held in RAM (re-run after a
  reflash). Fully operable with the DK buttons, so it works even before touch is
  calibrated.

Shared modal sub-screens: **KEYPAD** (reusable HEX entry for payloads, DEC entry
— with `.` and `+/-` — for numeric config fields) and the read-only **TX STATUS**
and **PING PONG STATS** views.

### Added (modules)

_The telemetry console's modules were retired 2026-09-25; `ui_widgets` and `touch_cal` live on in `src/tdma_console/` as the TFT unit's toolkit._

- **Staged RF config** — [`src/radio_cfg.c`](src/radio_cfg.c) /
  [`.h`](src/radio_cfg.h). Shadow + applied `lora_modem_config`, clamping
  setters/steppers, `radio_cfg_validate()` (datasheet limits), `radio_cfg_apply()`
  (the single commit point), dirty tracking, and value/summary formatters.
- **Payload buffer** — [`src/payload.c`](src/payload.c) /
  [`.h`](src/payload.h). Byte buffer + length, canned presets, hex format/parse.
- **UI toolkit + keypad** — [`src/tdma_console/ui_widgets.c`](src/tdma_console/ui_widgets.c) /
  [`.h`](src/tdma_console/ui_widgets.h). RGB565 blit primitives (CFB glyph data only — see the
  CFB note in the README), hit-testing, button and config value-row widgets, and
  the reusable HEX/DEC keypad modal.
- **Touch calibration** — [`src/tdma_console/touch_cal.c`](src/tdma_console/touch_cal.c) /
  [`.h`](src/tdma_console/touch_cal.h). In-RAM affine transform + a 5-point least-squares
  solver (mean-centred, single-precision, FPU-optional).
- **Ping/pong link test** — [`src/pingpong.c`](src/pingpong.c) /
  [`.h`](src/pingpong.h). A single dedicated RX thread that owns the radio while
  active (polls `lora_recv()` in short slices, sends ping/pong via `lora_send()`),
  mutex-guarded stats, and the 44-byte packet format.
- **Screen router** — [`src/console.c`](src/console.c). Main loop + screen state
  machine (HOME, CONFIG, PAYLOAD, KEYPAD, TX STATUS, CALIBRATE, PING PONG, PING
  PONG STATS), debounced touch capture, and single-owner drawing (only the main
  loop calls `display_write()`).

### Test functions & modes

_Retired 2026-09-25 with the streamline to two unit types (see that entry above); kept as history._

- **One-shot TX + radio status dump** — [`src/main.c`](src/main.c) (LoRa-send
  variant). Transmits a 16-byte payload once and dumps the SX1262 IRQ status and
  latched device errors over raw SPI (`dump_radio_status()`). Use for radio-only
  bring-up without the display stack.
- **SEND ONCE** — single on-demand transmit with an on-screen result (console).
- **PING PONG** — bidirectional RTT link test between a pair of units (console).
- **SD card boot-log self-test** — gated by `ENABLE_SD` in
  [`src/console.c`](src/console.c) (off by default). Mounts the FAT card, appends
  a timestamped boot line to `/SD:/BOOT.LOG`, and reads it back to validate the SD
  path end to end.

### Removed

_Retired 2026-09-25 with the streamline to two unit types (see that entry above); kept as history._

- **UART / serial console and all logging on the console build.** The telemetry
  console is now display-only — every `printk` / `LOG_*` call was removed from the
  console sources, and `CONFIG_SERIAL`, `CONFIG_CONSOLE`, `CONFIG_LOG`, and
  `CONFIG_PRINTK` are disabled for this build (in
  `boards/nrf5340dk_nrf5340_cpuapp_display.conf`). All state is shown on the TFT.
  This retired the `PINGPONG,*` CSV trace and the boot/status prints; the
  LoRa-send variant is unchanged and still reports over UART.

### Scripts & SDK preparation

These ready a fresh-from-Nordic NCS v3.2.1 install, which does **not** ship the
native SX126x LoRa driver this project uses. See the README's
[SDK setup](README.md#sdk-setup-fresh-from-nordic) section for the full rationale.

- [`scripts/setup_sdk.sh`](scripts/setup_sdk.sh) — One-shot SDK prep. Swaps the
  vendored driver in [`external/zephyr-lora-driver/`](external/zephyr-lora-driver)
  into `$ZEPHYR_BASE/drivers/lora` (backing up the stock copy to
  `drivers/lora.stock.bak`), then runs `apply.sh`. Idempotent; defaults
  `ZEPHYR_BASE` to `C:/ncs/v3.2.1/zephyr`.
- [`patches/apply.sh`](patches/apply.sh) — Applies the two compat patches with
  `git apply`. Idempotent: it reverse-checks each patch and skips ones already
  applied, and refuses to run if the native driver drop-in is absent.
- [`patches/0001-native-sx126x-spi-dt-spec-arity.patch`](patches/0001-native-sx126x-spi-dt-spec-arity.patch)
  — adds the trailing `delay` argument (`0`) to the native driver's
  `SPI_DT_SPEC_INST_GET` calls (v3.2.1's `spi.h` requires the 3-argument form).
- [`patches/0002-sx126x-base-binding-add-ldo-props.patch`](patches/0002-sx126x-base-binding-add-ldo-props.patch)
  — adds the `regulator-ldo` and `force-ldro` boolean properties to the
  `semtech,sx126x-base` devicetree binding, which the native driver reads.

> [!NOTE]
> The driver swap and patches live in the NCS install, not in this repo, and are
> reverted by any `west update` / SDK reinstall — re-run `scripts/setup_sdk.sh`
> and do a pristine build (`-p always`) afterward.

### Known limitations / next

- **Touch calibration is in-RAM only** on the TFT unit. That is deliberate:
  it is a mandatory power-on step lasting the session (see above).
- **TX records carry no frame counter.** `frame_ctr` is a *shared* frame
  number — the master owns it and the secondary adopts it verbatim from each
  beacon, so both units stamp the same value in a given frame, which is what
  makes cross-unit correlation work at all. But the engine does not expose its
  counter to the application, so `soak_log_tx()` writes 0 with `SOAK_F_NO_CTR`
  set. RX-to-RX alignment across the two files works today; pairing a unit's
  own TX against the peer's RX needs the counter added to
  `struct tdma_telemetry`.
- **`frame_ctr` wraps** at 65536 frames — **1.46 h at the current 20 ms
  slot** (it was 3.6 h at the 50 ms bring-up width), which the console's
  2-hour soak preset exceeds. Until this closes, keep runs that need
  cross-file pairing under ~1.4 h; a longer continuous run is still valid but
  only pairwise-alignable up to the first wrap.
  Within-file continuity is already wrap-safe (both firmware and
  decoder use modular deltas and ignore backward jumps as a peer restart);
  absolute cross-file alignment past a wrap would need the decoder to unwrap
  into a monotonic index, which is not built.
- **The 20 ms slot is soaked for up to three units.** The 30-minute
  two-unit acceptance soak passed (2026-08-18, above). Its worst
  |`phase_err`| of 75 µs leaves the 250 µs lock threshold ~3× margin, and
  the unit locked in 1.66 s. A 5-minute three-unit run passed too
  (2026-09-25, above): locks in 1.35 s and 2.79 s, worst 52 µs. With four
  units, a secondary still sees the beacon once per frame but has three
  peers' slots between corrections, and neither the phase envelope nor the
  acquisition transient has been measured there. Card #23 (garbled first
  packet after lock) must land before the four-unit soak: #23 predicts the
  third consecutive RX wraps onto the TX header every frame in a 4-slot
  geometry, which would confound the result. Its first-packet form is now
  confirmed on air (three-unit soak, above). Because SYNCING → RUNNING is
  one-way, the failure mode to watch for is a unit slow to lock or stuck
  in SYNCING — not one that drops out mid-run.
- **Three soak logs have come back with an 8 KB hole in them.** The master's file from
  the 30 min 50 ms run (commit `337ec96`) contains 128 consecutive records —
  16 sectors, sector-aligned — of garbage plus one sector of stale data, with
  `seq` running 12743 → 12544…12551 → 12872. Decoded naively that reads as
  `PER = 1.597 %` with 145 missed; excluding the hole the same file shows 0
  missed / 0 dup, and the engine counters agree (secondary `tx_done` 8997 vs
  master `rx_done` 8991, i.e. ~6 packets of real loss in 30 minutes). Cause
  not established — the size matches `SOAK_LOG_RING_DEPTH` exactly, but a
  producer-side ring drop leaves a `seq` gap without writing garbage, so this
  is a write-path or card fault, not a drop. It matters because at 20 ms the
  record rate roughly doubles: **check any one-sided loss for a hole before
  reading it as a radio result.**
  It recurred in the master's file from the 20 ms acceptance soak
  (`P0_30M_000.BIN`): again exactly 128
  records, 16 sectors, sector-aligned (file sectors 3668–3683). Five of the
  sectors are zeroed and eleven hold stale data from earlier card contents.
  A naive decode reads PER 26 %, yet the engine counters show no loss:
  master `rx_done` 22,480 = secondary `tx_done` 22,480. Both of those were
  on the master's card. A third came back in SEC 1's log from the
  three-unit soak (2026-09-25): file sectors 271–286, again 128 records
  with 40 zeroed and 88 stale, the same mix as the second. The unit was a
  secondary this time, so the fault follows a card or a unit, not the
  role. Worth checking whether it was the same physical card. Tracked as
  card #25 (master's SD card silently loses writes).
- **Field PER is unmeasured.** The 5-minute bench soak below closed at 0 % loss
  with ~45 dB of margin over SF5/BW500 sensitivity — that validates the stack,
  not the range. Loss behaviour at distance is still unknown.
- **Front end.** The rev 2 shield now carries an OLED + microSD front end for
  the field variant (see "Rev 2 shield / field variant"; bench bring-up
  pending). The TFT breakout used by the two consoles is still jumper-wired
  to the DK headers.
- **Field variant follow-ons:** move the soak runner into a module the TFT
  console and the field unit share; strip UART logging from the field
  variant once it is proven; handle a card swap while mounted, either by a
  remount on a DET change or with `cd-gpios` on the `sdhc` node if this
  tree's `sdhc_spi` supports it (DET is confirmed active-low on P1.12).

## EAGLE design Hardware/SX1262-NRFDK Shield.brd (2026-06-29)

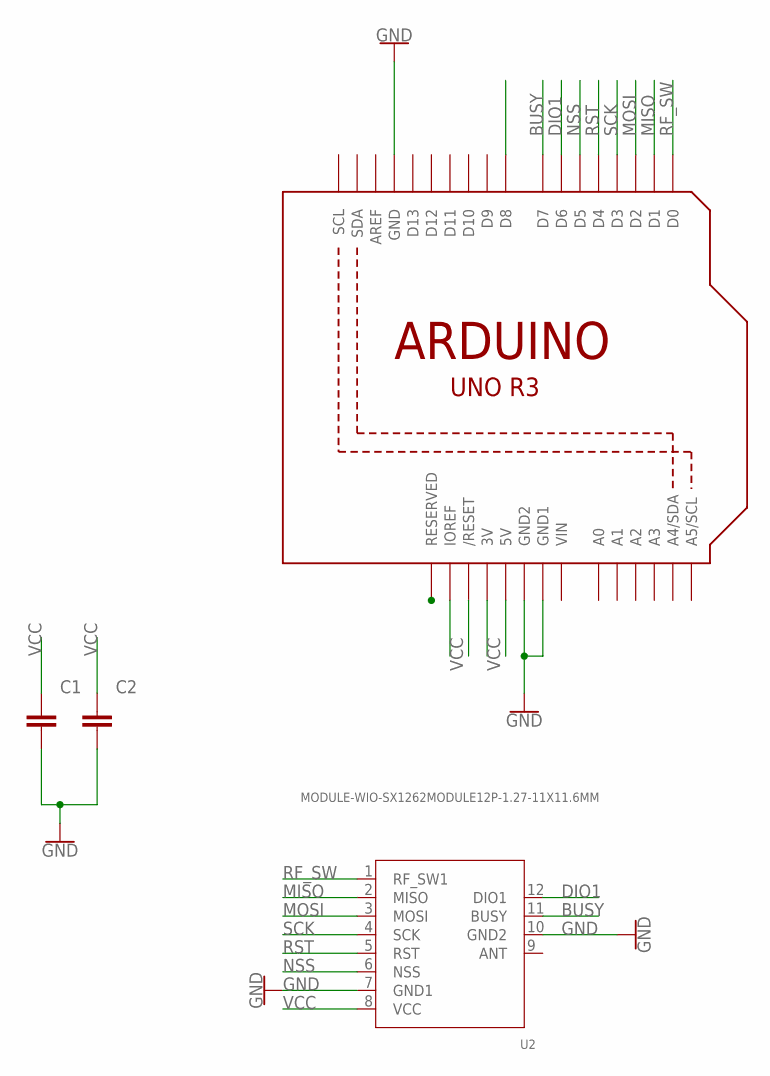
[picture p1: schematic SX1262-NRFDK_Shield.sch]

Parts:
C1, C2: C_CHIP-0805(2012-METRIC); CAPC2012X110
U1: ARDUINOR3-BPLACE
U2: MODULE-WIO-SX1262MODULE12P-1.27-11X11.6MM; MODULE12P-1.27-11X11.6MM

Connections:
BUSY: U1.D7, U2.11 (BUSY)
DIO1: U1.D6, U2.12 (DIO1)
GND: C1.2, C2.2, U1.GND, U1.GND1, U1.GND2, U2.7 (GND1), U2.10 (GND2)
MISO: U1.D1, U2.2 (MISO)
MOSI: U1.D2, U2.3 (MOSI)
NSS: U1.D5, U2.6 (NSS)
RF_SW: U1.D0, U2.1 (RF_SW1)
RST: U1.D4, U2.5 (RST)
SCK: U1.D3, U2.4 (SCK)
VCC: C1.1, C2.1, U1.3V, U1.IOREF, U1.RESERVED, U2.8 (VCC)
VIN: U1.VIN

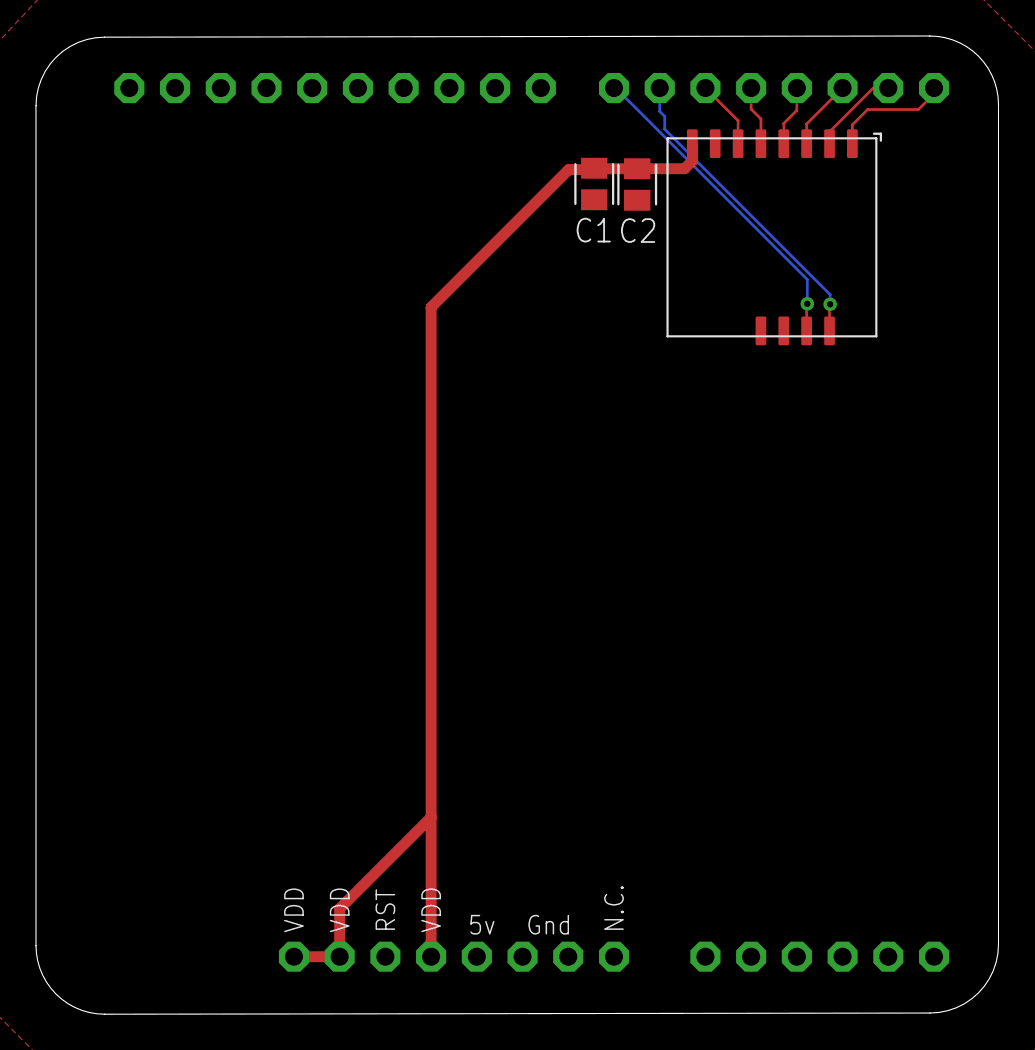
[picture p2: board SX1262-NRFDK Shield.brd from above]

Board: 2 copper layers, 53.5 x 54.3 mm, 4 parts (0 on the bottom side), 10 nets.

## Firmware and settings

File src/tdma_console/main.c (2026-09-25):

/*
 * Intercom TDMA field console (CONFIG_APP_TDMA_CONSOLE) — variant entry point.
 *
 * Field-test container UI for the TDMA radio layer (src/tdma): run timed soak
 * tests of the continuous TX/RX frame exchange and watch link telemetry live
 * on the TFT. Draws with the display toolkit (ui_widgets) and touch
 * calibration (touch_cal) kept from the retired telemetry console; the
 * radio path is exclusively the TDMA L1/L2 shim — the native driver is
 * init-only. This file is only compiled for CONFIG_APP_TDMA_CONSOLE.
 *
 * Display-only build (no UART / log / shell). One firmware image serves every
 * unit: the unit (MASTER in slot 0, or SEC 1..3) is picked at power-on and
 * locks at the first soak start (tdma_init() is once-only) — reboot to
 * change it. Every PHY parameter is a compile-time constant in tdma.h except
 * TX power, which is adjustable from HOME (applied by the engine before the
 * next transmit).
 *
 * Power-on sequence, both steps mandatory and session-only: TOUCH CAL (the
 * transform is RAM-only in touch_cal, so every boot re-runs it) then SELECT
 * UNIT. Calibration comes first so the unit can be chosen by touch. HOME is
 * unreachable until both are done, so no soak can run uncalibrated or on an
 * unset unit. Neither is reachable from HOME afterwards — reboot to redo
 * either; the selected unit is shown in the HOME header.
 *
 * Screens: HOME -> {SOAK PICK -> SOAK, TX PWR keypad, FILES}. The soak
 * screen shows per-soak deltas of the engine telemetry plus frame-counter
 * continuity stats (received / missed / duplicate peer frames), which catch
 * losses the CRC counters cannot.
 *
 * FILES is a minimal SD browser: list, delete (two-press confirm), move
 * between the fixed top-level drawers (DRAWER0-3, created on demand), and an
 * optional label appended to a filename via the alpha keypad. The soak-pick
 * screen selects which drawer (or the root) new logs land in. All card I/O
 * is submitted to the soak_log writer thread and polled, never blocking the
 * UI; log files are named <PWR>_<DUR>_NNN.BIN (e.g. M9_5M_000.BIN).
 *
 * Every soak also writes a binary record log to the microSD card (soak_log ->
 * sd_log): one 64-byte record per received packet — payload included — plus
 * TX and periodic counter records. Logging is best-effort and never aborts a
 * run; the soak screen carries the file name, record count and drop count.
 * Decode with tools/decode_soak_log.py.
 *
 * SPDX-License-Identifier: Apache-2.0
 */

#include <zephyr/kernel.h>
#include <zephyr/input/input.h>
#include <zephyr/sys/atomic.h>
#include <zephyr/sys/util.h>
#include <string.h>
#include <stdio.h>
#include <stdlib.h>

#include "ui_widgets.h"
#include "touch_cal.h"
#include "tdma.h"
#include "soak_log.h"

/* ---- Layout ----
 * Portrait, 240x320 (see the rotation note in the TFT overlay). Rows use
 * fixed heights rather than dividing the body: portrait leaves 272 px of body,
 * and splitting that between two menu rows would produce 130 px-tall buttons.
 * Text is 10 px/char, so a full-width line is 23 characters at MARG.
 */
#define BORDER_PX 3
#define MARG 4

#define ROW_H	 56	/* HOME menu row */
#define ROW_GAP	 10
#define FLIP_W	120	/* the small 180-deg view-flip button */
#define FLIP_H	 34
#define PICK_H	 38	/* soak-pick rows (log-dir + durations + BACK) */
#define PICK_GAP  8
#define ROLE_H	 48	/* unit-select buttons (one per slot) */
#define ROLE_GAP  8
#define BR_ROW_H 22	/* file-browser list row */
#define ACT_H	 44	/* stacked action buttons (file act / move) */
#define ACT_GAP	  8

/* ---- Navigation (posted by the button callback, consumed in main) ---- */
enum nav_action {
	NAV_NONE = 0,
	NAV_UP,
	NAV_DOWN,
	NAV_OK,
	NAV_BACK,
};
static atomic_t nav_event = ATOMIC_INIT(NAV_NONE);

/* ---- Touch tap (debounced; raw latched in the callback, mapped in main) ---- */
static volatile int touch_x, touch_y;
static volatile bool touch_down;
static volatile bool touch_latched;
static volatile int tap_raw_x, tap_raw_y;
static atomic_t tap_ready = ATOMIC_INIT(0);

/* ---- Screen state machine ---- */
enum screen_id {
	SCR_HOME = 0,
	SCR_SOAK_PICK,
	SCR_SOAK,
	SCR_KEYPAD,	/* TX power / label entry */
	SCR_CALIBRATE,
	SCR_ROLE_PICK,	/* power-on role selection */
	SCR_FILES,	/* SD file browser: list + new-drawer */
	SCR_FILE_ACT,	/* per-file actions: delete / move / label */
	SCR_FILE_MOVE,	/* move destination pick */
};
static enum screen_id screen = SCR_HOME;

/*
 * Touch calibration is a mandatory power-on step: the transform lives in RAM
 * only (touch_cal), so every boot starts from the identity mapping and taps
 * would land nowhere useful until it is run. main() forces the CAL screen
 * before anything else and this flag blocks cancelling out of it; it clears
 * once a fit is accepted. Session-only by design — no flash persistence.
 */
static bool cal_required = true;

/*
 * Unit selection (role + TX slot) is the second half of the power-on
 * sequence, run once calibration is accepted: with a working transform the
 * choice can be made by touch. Like the calibration pass there is no way out
 * but choosing — HOME is unreachable until this clears, so no soak can start
 * on an unset unit. role_sel indexes the slot: 0 = MASTER, 1-3 = SEC n.
 */
static bool role_required = true;
static int role_sel;

/* ---- Log destination + file browser state ----
 * dir index 0 is the card root; 1..SD_DRAWERS are the fixed drawer names. The
 * soak logger points at log_dir_idx (selectable on the soak-pick screen); a
 * missing drawer is created when a log actually opens there.
 */
#define SD_DRAWERS 4
static const char *const drawer_name[SD_DRAWERS + 1] = {
	"", "DRAWER0", "DRAWER1", "DRAWER2", "DRAWER3",
};
static int log_dir_idx;			/* 0 = "/" */

#define BR_LIST_MAX 64
static struct sd_dirent br_ents[BR_LIST_MAX];
static int br_count;
static int br_dir;			/* browsed dir, same indexing */
static int br_sel;
static int br_scroll;
static bool br_busy;			/* fs op in flight on the writer */
static bool br_truncated;		/* directory had > BR_LIST_MAX entries */
static char br_msg[24];			/* footer status / error */
static enum sd_fsop_op br_op;		/* op awaiting completion */
static char fa_name[SD_FSOP_NAME_MAX];	/* file the action menu targets */
static int fa_sel;
static bool fa_confirm_del;
static int mv_sel;

/* What the keypad edits when SCR_KEYPAD closes. */
static enum { KP_FOR_POWER, KP_FOR_LABEL } kp_purpose;

static int home_sel;
static int pick_sel;
static char home_msg[28] = "";

/* ---- Engine / unit state ----
 * The unit is picked at power-on as one choice: its TX slot, with the role
 * following from it. Slot 0 is the master, which beacons the frame timing;
 * slots 1-3 are secondaries. Picking them together means a master can never
 * sit outside slot 0. Two units must still not pick the same slot.
 */
static enum tdma_role role = TDMA_ROLE_SECONDARY; /* fail-safe default: two
						   * unset units just listen
						   * instead of colliding. */
static uint8_t my_slot = 1;	/* SEC 1 until picked */
static bool engine_inited;	/* unit locks once true */
static int tx_power_dbm = TDMA_TX_POWER_DBM;

/* ---- Soak test state ----
 * Split ownership: the soak data thread (below) owns every field while a
 * run is active; the UI loop only starts/stops a run and reads the fields
 * to draw them. Reads for drawing are deliberately unlocked -- a counter
 * caught mid-update misdraws one frame of a diagnostic, and holding a lock
 * across a full-screen SPI repaint would reintroduce exactly the stall this
 * split exists to remove.
 */
static const struct {
	const char *label;
	int64_t ms;		/* 0 = run until STOP */
} soak_durations[] = {
	{ "5 MIN", 5 * 60 * 1000LL },
	{ "30 MIN", 30 * 60 * 1000LL },
	{ "2 HOURS", 120 * 60 * 1000LL },
	{ "CONTINUOUS", 0 },
};
/* Rows on the pick screen: log-dir selector, durations, BACK. */
#define PICK_COUNT (ARRAY_SIZE(soak_durations) + 2)
#define PICK_ROW_DIR  0
#define PICK_ROW_BACK ((int)PICK_COUNT - 1)

static struct {
	bool active;
	bool done;		/* finished (elapsed or STOP); stats frozen */
	int64_t start_ms;
	int64_t duration_ms;
	struct tdma_telemetry snap;	/* engine totals at soak start */

	/* Frame-counter continuity per transmitting slot: the peer's counter
	 * advances by one per frame, so a gap is a missed frame and a repeat
	 * is a stale retransmit — content-level loss the CRC counters miss.
	 */
	uint16_t last_ctr[TDMA_SLOT_COUNT];
	bool have_ctr[TDMA_SLOT_COUNT];
	uint32_t rx_ok;
	uint32_t missed;
	uint32_t dup;

	int16_t last_rssi;
	int8_t last_snr;
	uint8_t seq;		/* TX pattern sequence */

	/*
	 * Staged-payload tracking, so the log records transmissions rather
	 * than submissions. tdma_tx_submit() succeeds whenever the engine's
	 * stage buffer is free — several times per frame at the data thread's
	 * tick — but only one payload per frame is actually sent; the rest
	 * are overwritten in place. We therefore hold a payload "armed" and
	 * only log it once the engine's tx_done confirms it went out.
	 */
	bool tx_armed;
	uint8_t tx_payload[TDMA_PAYLOAD_LEN];
	uint32_t tx_done_at_arm;

	/*
	 * Staging headroom, measured as the worst gap between consecutive
	 * data-thread passes while a run is active.
	 *
	 * This is deliberately NOT the interval between successful submits.
	 * A submit can only follow the previous transmission (the tx_armed
	 * gate above), so submit-to-submit has a floor of one frame period —
	 * 80 ms at the 20 ms width — and is longer still across acquisition,
	 * when a secondary cannot transmit at all. Measured that way it
	 * exceeds SOAK_STAGE_BUDGET_US even on a perfectly healthy unit,
	 * because the budget is a within-frame deadline and the interval is
	 * not.
	 *
	 * What the budget actually constrains is how long after the engine's
	 * TxDone the application takes to notice and re-stage, and that is
	 * bounded by how promptly this thread runs. So: worst pass-to-pass
	 * latency, against the budget. Under it, staging can never be late
	 * and stale_retx is impossible; approaching it is the warning.
	 */
	int64_t last_tick_ms;
	uint32_t tick_gap_max_ms;

	/*
	 * Set by the data thread when the elapsed limit is reached; the UI
	 * loop performs the teardown. soak_finish() closes the log, which
	 * waits on the writer thread for up to 5 s — that must never run on
	 * the cooperative data thread.
	 */
	bool expired;
} soak;

static int64_t soak_last_draw_ms;

/* Counter-snapshot cadence: one STATS record per second is negligible against
 * the packet stream but bounds how stale the counters are if a run is cut off.
 */
#define SOAK_STATS_PERIOD_MS 1000
static int64_t soak_last_stats_ms;

/*
 * Payload-staging budget: how long the application has, after its own TxDone,
 * to hand the engine a fresh payload before the engine re-sends the previous
 * one and counts a stale_retx.
 *
 * The engine takes a staged payload in rx_slot_slack_work(), which runs at
 * every RX-slot entry. For a unit transmitting in slot S the last such entry
 * before its next TX comes (TDMA_SLOT_COUNT - 1) slots later, so the usable
 * window runs from TxDone — TX_START_LATENCY + TOA after the boundary — to
 * that entry. Role-symmetric: the arithmetic is the same for any slot_id.
 *
 *   (SLOT_COUNT - 1) * SLOT_DURATION - (TX_START_LATENCY + TOA)
 *
 * 141.7 ms at the 50 ms bring-up width, 51.7 ms at the 20 ms production
 * width — the flip cut it by 63 %. That is why staging cannot live on the UI
 * loop: one draw_soak_dynamic() pass clears the body with a full-width SPI
 * fill and overruns 51.7 ms on its own, so every repaint dropped a frame's
 * payload. The same cost fitted inside the 50 ms-width budget, which is why
 * it only surfaced after the flip.
 *
 * A 4-unit frame relaxes this slightly — a packet landing in the last RX slot
 * triggers a second slack pass — but the guaranteed window is the one above.
 */
#define SOAK_STAGE_BUDGET_US \
	((TDMA_SLOT_COUNT - 1) * TDMA_SLOT_DURATION_US - \
	 (TDMA_TX_START_LATENCY_US + TDMA_TOA_US))

BUILD_ASSERT(SOAK_STAGE_BUDGET_US > 0,
	     "TX latency + time-on-air must leave a staging window");

/*
 * Data-thread tick. The engine needs one submit per frame; polling at 2 ms
 * keeps worst-case staging latency an order of magnitude inside the budget,
 * and the work per tick is a mutex plus a handful of compares. Slower when
 * idle, since nothing can arrive between runs.
 */
#define SOAK_DATA_TICK_MS	2
#define SOAK_DATA_IDLE_MS	50
#define SOAK_DATA_STACK		1536

/*
 * Cooperative, one notch below the radio thread (K_PRIO_COOP(4)) and above
 * every preemptible thread, so no amount of drawing, touch handling or card
 * I/O can delay a payload. It never blocks on anything but its own sleep and
 * never touches SPI, so sitting above the UI costs the UI nothing.
 */
#define SOAK_DATA_PRIO		K_PRIO_COOP(6)

/* Guards the soak struct's lifecycle transitions against the data thread. */
static K_MUTEX_DEFINE(soak_lock);

/* Set by any thread to ask main to redraw. */
static atomic_t screen_dirty = ATOMIC_INIT(0);

static void mark_dirty(void)
{
	atomic_set(&screen_dirty, 1);
}

/* ---------------------------------------------------------------------------
 * Input callbacks (input thread context; post events only, never draw)
 * ------------------------------------------------------------------------- */
static void touch_cb(struct input_event *evt, void *user_data)
{
	ARG_UNUSED(user_data);

	switch (evt->code) {
	case INPUT_ABS_X:
		touch_x = evt->value;
		break;
	case INPUT_ABS_Y:
		touch_y = evt->value;
		break;
	case INPUT_BTN_TOUCH:
		touch_down = evt->value != 0;
		break;
	default:
		break;
	}

	if (!evt->sync) {
		return;
	}

	if (touch_down && !touch_latched) {
		touch_latched = true;
		tap_raw_x = touch_x;
		tap_raw_y = touch_y;
		atomic_set(&tap_ready, 1);
	} else if (!touch_down) {
		touch_latched = false;
	}
}
INPUT_CALLBACK_DEFINE(DEVICE_DT_GET(DT_CHOSEN(zephyr_touch)), touch_cb, NULL);

/* DK buttons -> nav. B1=UP(KEY_0) B2=DOWN(KEY_1) B3=OK(KEY_2) B4=BACK(KEY_3). */
static void button_cb(struct input_event *evt, void *user_data)
{
	ARG_UNUSED(user_data);

	if (evt->type != INPUT_EV_KEY || evt->value == 0) {
		return; /* press only */
	}

	enum nav_action action;

	switch (evt->code) {
	case INPUT_KEY_0:
		action = NAV_UP;
		break;
	case INPUT_KEY_1:
		action = NAV_DOWN;
		break;
	case INPUT_KEY_2:
		action = NAV_OK;
		break;
	case INPUT_KEY_3:
		action = NAV_BACK;
		break;
	default:
		return;
	}

	atomic_set(&nav_event, action);
}
INPUT_CALLBACK_DEFINE(DEVICE_DT_GET(DT_PATH(buttons)), button_cb, NULL);

/* ---------------------------------------------------------------------------
 * Geometry / chrome helpers
 * ------------------------------------------------------------------------- */
static int body_top(void)
{
	return MARG + ui_body_h() + 4;
}

static int body_bot(void)
{
	return ui_disp_h() - MARG - ui_body_h() - 4;
}

static void draw_border(void)
{
	int w = ui_disp_w();
	int h = ui_disp_h();

	ui_fill_rect(0, 0, w, BORDER_PX, COLOR_WHITE);
	ui_fill_rect(0, h - BORDER_PX, w, BORDER_PX, COLOR_WHITE);
	ui_fill_rect(0, 0, BORDER_PX, h, COLOR_WHITE);
	ui_fill_rect(w - BORDER_PX, 0, BORDER_PX, h, COLOR_WHITE);
}

static void draw_header(const char *title)
{
	int w = ui_disp_w();
	int bh = ui_body_h();

	ui_fill_rect(BORDER_PX, MARG, w - 2 * BORDER_PX, bh, COLOR_BLACK);
	ui_text(MARG, MARG, title, COLOR_WHITE, COLOR_BLACK);
}

static void draw_footer_text(const char *s)
{
	int w = ui_disp_w();
	int bh = ui_body_h();
	int fy = ui_disp_h() - MARG - bh;

	ui_fill_rect(BORDER_PX, fy, w - 2 * BORDER_PX, bh, COLOR_BLACK);
	ui_text(MARG, fy, s, COLOR_WHITE, COLOR_BLACK);
}

/* Fixed PHY summary + the one adjustable knob. */
static void draw_footer_summary(void)
{
	char s[28];

	snprintf(s, sizeof(s), "915MHz SF5/500k %+ddBm", tx_power_dbm);
	draw_footer_text(s);
}

/* A unit by slot: "MASTER" for slot 0, "SEC 1".."SEC 3" otherwise. */
static const char *unit_name(uint8_t slot)
{
	static const char *const name[TDMA_SLOT_COUNT] = {
		"MASTER", "SEC 1", "SEC 2", "SEC 3",
	};

	return name[slot % TDMA_SLOT_COUNT];
}

static const char *role_str(void)
{
	return unit_name(my_slot);
}

/* h:mm:ss, always sortable at a glance in the field (hours wrap at 99). */
static void fmt_dur(char *out, size_t n, int64_t ms)
{
	unsigned s = (unsigned)(ms / 1000);

	snprintf(out, n, "%u:%02u:%02u", (s / 3600) % 100, (s / 60) % 60,
		 s % 60);
}

/* ---------------------------------------------------------------------------
 * HOME
 * ------------------------------------------------------------------------- */
/*
 * HOME is deliberately minimal. Touch calibration and role selection are
 * power-on steps only (see the sequence at the top of this file) — reboot to
 * redo either. TX power stays because it is the one PHY parameter meant to be
 * swept from the bench, and is where further run parameters will land.
 */
enum home_row {
	HR_SOAK = 0,
	HR_POWER,
	HR_FILES,
	HR_FLIP,	/* small button, sits apart from the menu rows */
	HR_COUNT,
};

static void home_row_rect(int i, int *x, int *y, int *w, int *h)
{
	if (i == HR_FLIP) {
		/* Deliberately small and set apart at the foot of the body:
		 * it changes how the screen is held, not what the test does.
		 */
		*w = FLIP_W;
		*h = FLIP_H;
		*x = (ui_disp_w() - FLIP_W) / 2;
		*y = body_bot() - FLIP_H;
		return;
	}

	*x = MARG;
	*w = ui_disp_w() - 2 * MARG;
	*h = ROW_H;
	*y = body_top() + i * (ROW_H + ROW_GAP);
}

static void draw_home(void)
{
	char val[16];
	char hdr[28];

	/* Role moved out of the menu, so carry it in the header: with two
	 * identical units on the bench it is the one thing you cannot infer by
	 * looking at them.
	 */
	snprintf(hdr, sizeof(hdr), "FIELD TEST: %s", role_str());
	draw_header(hdr);

	for (int i = 0; i < HR_COUNT; i++) {
		int x, y, w, h;

		home_row_rect(i, &x, &y, &w, &h);

		switch (i) {
		case HR_SOAK:
			ui_button(x, y, w, h, "SOAK TEST", home_sel == i);
			break;
		case HR_POWER:
			snprintf(val, sizeof(val), "%+d dBm", tx_power_dbm);
			ui_value_row(x, y, w, h, "TX pwr", val, false,
				     home_sel == i, false);
			break;
		case HR_FILES:
			ui_button(x, y, w, h, "FILES", home_sel == i);
			break;
		case HR_FLIP:
			ui_button(x, y, w, h, ui_flipped() ? "FLIP ^" : "FLIP v",
				  home_sel == i);
			break;
		default:
			break;
		}
	}

	if (home_msg[0]) {
		draw_footer_text(home_msg);
	} else {
		draw_footer_summary();
	}
}

/* ---------------------------------------------------------------------------
 * SOAK PICK (duration buttons)
 * ------------------------------------------------------------------------- */
static void pick_btn_rect(int i, int *x, int *y, int *w, int *h)
{
	int stack = (int)PICK_COUNT * PICK_H + ((int)PICK_COUNT - 1) * PICK_GAP;
	int top = body_top() + (body_bot() - body_top() - stack) / 2;

	*x = MARG;
	*w = ui_disp_w() - 2 * MARG;
	*h = PICK_H;
	*y = top + i * (PICK_H + PICK_GAP);
}

/* "/" or the drawer name, for the selector row and browser headers. */
static const char *dir_label(int idx)
{
	return (idx == 0) ? "/" : drawer_name[idx];
}

static void draw_soak_pick(void)
{
	char hdr[28];

	snprintf(hdr, sizeof(hdr), "SOAK: %s", role_str());
	draw_header(hdr);

	for (int i = 0; i < (int)PICK_COUNT; i++) {
		int x, y, w, h;

		pick_btn_rect(i, &x, &y, &w, &h);
		if (i == PICK_ROW_DIR) {
			ui_value_row(x, y, w, h, "LOG",
				     dir_label(log_dir_idx), true,
				     pick_sel == i, false);
		} else if (i == PICK_ROW_BACK) {
			ui_button(x, y, w, h, "BACK", pick_sel == i);
		} else {
			ui_button(x, y, w, h, soak_durations[i - 1].label,
				  pick_sel == i);
		}
	}

	draw_footer_summary();
}
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
int main(void)
{
	bool ui_ok = ui_init();

	touch_cal_init();

	/* tdma_init() is deferred to the first soak start so the role stays
	 * selectable on HOME until then.
	 */

	/* No UART on this build; if the display failed there is nothing to
	 * report to, so just halt.
	 */
	if (!ui_ok) {
		k_sleep(K_FOREVER);
	}

	/* Mandatory power-on calibration: the transform is RAM-only, so the
	 * console opens on the CAL screen and cal_required keeps it there until
	 * a fit is accepted. Collection uses the RAW samples, so it works
	 * correctly from the identity mapping.
	 */
	cal_start();

	ui_clear(COLOR_BLACK);
	draw_border();
	draw_current();

	enum screen_id last = screen;

	while (1) {
		enum nav_action a = atomic_set(&nav_event, NAV_NONE);
		int rawx = 0, rawy = 0, sx = 0, sy = 0;
		bool tap = atomic_cas(&tap_ready, 1, 0);

		if (tap) {
			rawx = tap_raw_x;
			rawy = tap_raw_y;
			touch_cal_apply(rawx, rawy, &sx, &sy);
			/* The touch controller's axes are fixed to the glass,
			 * so a 180-deg flipped view needs the mapped point
			 * mirrored before any hit test sees it.
			 */
			ui_flip_point(&sx, &sy);
		}

		if (a != NAV_NONE) {
			handle_nav(a);
		}
		if (tap) {
			handle_tap(sx, sy, rawx, rawy);
		}

		/*
		 * The data plane runs on soak_data_tid, not here — a repaint
		 * below overruns SOAK_STAGE_BUDGET_US on its own. All the UI
		 * still owes it is the teardown, which blocks on the card
		 * writer and so cannot run on that thread.
		 */
		if (soak.expired) {
			soak_finish();
		}

		/* Browser card-op completions (writer thread finishes them). */
		br_poll();

		bool dirty = atomic_cas(&screen_dirty, 1, 0);
		bool changed = (screen != last);

		if (a != NAV_NONE || tap || dirty || changed) {
			if (changed) {
				ui_clear(COLOR_BLACK);
				draw_border();
			}
			draw_current();
			last = screen;
		}

		/* Live-refresh the soak stats while the screen is up. */
		if (screen == SCR_SOAK && soak.active) {
			int64_t now = k_uptime_get();

			if (now - soak_last_draw_ms >= 250) {
				soak_last_draw_ms = now;
				draw_soak_dynamic();
			}
		}

		k_sleep(K_MSEC(20));
	}

	return 0;
}

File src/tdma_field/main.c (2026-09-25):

/*
 * Intercom TDMA field unit (CONFIG_APP_TDMA_FIELD): variant entry point for
 * the rev 2 shield. SSD1306 128x64 OLED on i2c1, microSD on spi4, Wio-SX1262
 * on spi2 (boards/nrf5340dk_nrf5340_cpuapp_shield.overlay).
 *
 * The TDMA field console's soak runner on a buttons-only, essentials-only UI.
 * The runner (soak_start / soak_finish / soak_data_step / soak_data_fn /
 * soak_data_tid) and button_cb are copied from src/tdma_console/main.c.
 * Moving the runner into a module both consoles share is a follow-on.
 * Record logging uses the console's sd_log / soak_log, which do not depend
 * on the display (linked from src/tdma_console, see CMakeLists.txt).
 *
 * One image serves every unit. Power-on goes straight to UNIT, which is
 * mandatory: MASTER (slot 0) or SEC 1..3, one TX slot per unit. The choice
 * locks at the first tdma_init(); reboot to change it.
 *
 * The UI is a cycle menu: one item per screen, drawn as large as it fits.
 * UP/DOWN cycles, OK acts, B4 goes back. HOME cycles three items:
 *   SOAK     cycle 5 min / 30 min / 2 h / continuous, OK starts. The live
 *            screen cycles pages: time, RX, TX, phase, link, log, latency.
 *   TX PWR   OK to edit: UP/DOWN steps -9..+22 dBm, default +0 dBm
 *   SD CARD  pages: .BIN count + newest file, free space, card-detect
 * Buttons: B1 UP, B2 DOWN, B3 OK, B4 BACK. B4 also stops a running soak.
 * Entering HOME rescans the card on the soak_log writer thread; the UI
 * never calls FatFs itself.
 *
 * Drawing goes through CFB, which rebuilds the whole 1 KB frame and pushes
 * it every time. At 400 kHz that is ~25 ms of I2C on this thread and nowhere
 * else. The soak data thread outranks it and never touches a bus, so a
 * repaint cannot delay a payload. The live soak screen repaints at 2 Hz.
 *
 * UART logging stays on for bring-up. Boot, card scans, card-detect changes,
 * role, TX power and soak start/stop are logged, but nothing per packet.
 *
 * SPDX-License-Identifier: Apache-2.0
 */

#include <zephyr/kernel.h>
#include <zephyr/device.h>
#include <zephyr/display/cfb.h>
#include <zephyr/drivers/display.h>
#include <zephyr/drivers/gpio.h>
#include <zephyr/input/input.h>
#include <zephyr/logging/log.h>
#include <zephyr/sys/atomic.h>
#include <zephyr/sys/util.h>
#include <stdio.h>
#include <string.h>

#include "tdma.h"
#include "soak_log.h"

LOG_MODULE_REGISTER(tdma_field, LOG_LEVEL_INF);

/* Boot TX power for this variant (the engine's own default is +22 dBm). */
#define FIELD_TX_POWER_DBM	0

/* Live soak repaint cadence: <= 2 Hz keeps the I2C cost off the budget. */
#define SOAK_DRAW_PERIOD_MS	500

#define SPLASH_MS		1200

/* ---- Navigation (posted by the button callback, consumed in main) ---- */
enum nav_action {
	NAV_NONE = 0,
	NAV_UP,
	NAV_DOWN,
	NAV_OK,
	NAV_BACK,
};
static atomic_t nav_event = ATOMIC_INIT(NAV_NONE);

/* ---- Screen state machine ---- */
enum screen_id {
	SCR_ROLE_PICK = 0,	/* power-on, mandatory */
	SCR_HOME,
	SCR_SOAK_PICK,
	SCR_SOAK,
	SCR_SD,
};
static enum screen_id screen = SCR_ROLE_PICK;

enum home_row {
	HR_SOAK = 0,
	HR_POWER,
	HR_SD,
	HR_COUNT,
};
static int home_sel;
static bool tx_edit;		/* HR_POWER is being stepped in place */
static char home_msg[24] = "";

static int role_sel;
static int pick_sel;
static char pick_msg[20] = "";

/* The live soak and SD screens are cycles of one-value pages. */
enum soak_page {
	SP_TIME = 0,
	SP_RX,
	SP_TX,
	SP_SYNC,
	SP_LINK,
	SP_LOG,
	SP_LAT,
	SP_COUNT,
};
static int soak_page;

enum sd_page {
	SDP_FILES = 0,
	SDP_FREE,
	SDP_DET,
	SDP_COUNT,
};
static int sd_page;

/* ---- Engine / unit state ----
 * The unit is picked at power-on as one choice: its TX slot, with the role
 * following from it. Slot 0 is the master, which beacons the frame timing;
 * slots 1-3 are secondaries. Picking them together means a master can never
 * sit outside slot 0. Two units must still not pick the same slot.
 */
static enum tdma_role role = TDMA_ROLE_SECONDARY; /* fail-safe default: two
						   * unset units just listen
						   * instead of colliding. */
static uint8_t my_slot = 1;	/* SEC 1 until picked */
static bool engine_inited;	/* unit locks once true */
static int tx_power_dbm = FIELD_TX_POWER_DBM;

/* ---- Soak test state ----
 * Split ownership: the soak data thread (below) owns every field while a
 * run is active; the UI loop only starts/stops a run and reads the fields
 * to draw them. Reads for drawing are deliberately unlocked -- a counter
 * caught mid-update misdraws one frame of a diagnostic, and holding a lock
 * across a repaint would reintroduce exactly the stall this split exists to
 * remove.
 */
static const struct {
	const char *label;
	int64_t ms;		/* 0 = run until STOP */
} soak_durations[] = {
	{ "5 MIN", 5 * 60 * 1000LL },
	{ "30 MIN", 30 * 60 * 1000LL },
	{ "2 HOURS", 120 * 60 * 1000LL },
	{ "CONTINUOUS", 0 },
};
#define PICK_COUNT ((int)ARRAY_SIZE(soak_durations))

static struct {
	bool active;
	bool done;		/* finished (elapsed or STOP); stats frozen */
	int64_t start_ms;
	int64_t duration_ms;
	struct tdma_telemetry snap;	/* engine totals at soak start */

	/* Frame-counter continuity per transmitting slot: the peer's counter
	 * advances by one per frame, so a gap is a missed frame and a repeat
	 * is a stale retransmit — content-level loss the CRC counters miss.
	 */
	uint16_t last_ctr[TDMA_SLOT_COUNT];
	bool have_ctr[TDMA_SLOT_COUNT];
	uint32_t rx_ok;
	uint32_t missed;
	uint32_t dup;

	int16_t last_rssi;
	int8_t last_snr;
	uint8_t seq;		/* TX pattern sequence */

	/*
	 * Staged-payload tracking, so the log records transmissions rather
	 * than submissions. tdma_tx_submit() succeeds whenever the engine's
	 * stage buffer is free — several times per frame at the data thread's
	 * tick — but only one payload per frame is actually sent; the rest
	 * are overwritten in place. We therefore hold a payload "armed" and
	 * only log it once the engine's tx_done confirms it went out.
	 */
	bool tx_armed;
	uint8_t tx_payload[TDMA_PAYLOAD_LEN];
	uint32_t tx_done_at_arm;

	/*
	 * Staging headroom: the worst gap between consecutive data-thread
	 * passes while a run is active, against SOAK_STAGE_BUDGET_US. Under
	 * budget, staging can never be late and stale_retx is impossible. See
	 * the console's copy for why this is pass-to-pass latency rather than
	 * the interval between submits.
	 */
	int64_t last_tick_ms;
	uint32_t tick_gap_max_ms;

	/*
	 * Set by the data thread when the elapsed limit is reached; the UI
	 * loop performs the teardown. soak_finish() closes the log, which
	 * waits on the writer thread for up to 5 s — that must never run on
	 * the cooperative data thread.
	 */
	bool expired;
} soak;

static int64_t soak_last_draw_ms;

/* Counter-snapshot cadence: one STATS record per second is negligible against
 * the packet stream but bounds how stale the counters are if a run is cut off.
 */
#define SOAK_STATS_PERIOD_MS 1000
static int64_t soak_last_stats_ms;
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

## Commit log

2026-06-29 EAGLE Files for the SX1262 Shield
    Dead-simple Arduino shield for quickly attaching the SX1262 to an NRF DK.
    [SX1262-NRFDK Shield.brd, SX1262-NRFDK_Shield.sch]
2026-06-29 Update hardware entry file with assembly details
    Added additional information about hardware assembly.
2026-06-29 DK solder bridge instructions
2026-07-05 removed UART and logging
2026-07-06 add tdma layer with test frame
2026-07-21 tdma: fix dead RX windows, HFCLK drift, and a guard-lead regression
    Bench-tested master+secondary and found three independent bugs, using
    new per-slot diagnostic counters to see the chip's actual state instead
    of inferring it from DIO1 activity alone:
    - Per-slot SetRx timeout left alternating RX windows dead: armed and
    confirmed in RX by GetStatus, but never raising a DIO1 edge. This was
    the real cause of the secondary's marginal beacon reception, not the
    "benign 2:1 timeout ratio" the previous entry assumed. Fixed by
    running RX continuously (SX126X_RX_CONTINUOUS) and letting the slot
    boundary itself end the window.
    - HFCLK was free-running on the internal RC oscillator (nothing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
    [main.c, tdma.h, tdma_port.c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]
2026-07-21 tdma: add the field console variant (soak-test applet on the TFT)
    New fourth firmware variant, CONFIG_APP_TDMA_CONSOLE: the bench
    diagnostics sequence packaged as an on-device applet for field soak
    testing of the TDMA link. One image serves both units — role is picked
    on the HOME screen and locks at the first soak start (defaults to
    SECONDARY so two unconfigured units listen instead of colliding).
    - src/tdma_console/main.c: HOME -> SOAK TEST (5 min / 30 min / 2 h /
    continuous) with live per-soak telemetry deltas, frame-counter
    continuity stats (miss/dup — content-level loss the CRC counters
    can't see), TX power keypad, and the console's 5-point TOUCH CAL
    flow. Display-only; no U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
    [main.c, tdma.h, tdma_radio.c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]
2026-07-31 attached sd card logs to soak tests
2026-07-31 soak test log writes to SD card
    Also moved the touch calibration and role selection to a power on sequence
2026-08-04 added sd card file system
    [SOAK001.CSV, SOAK001_rows.csv, SOAK003_rows.csv]
2026-08-12 tdma: add per-slot and TxDone boundary-to-DIO1 dt telemetry
    TDMA_TX_START_LATENCY_US is defined as the chip's SetTx-to-preamble
    latency but consumed by tdma_core_sync_feed() as the full boundary-to-air
    delay, which also contains the radio-thread wake and the slot_tx_enter
    SPI sequence. Before redefining the constant from measurement, add the
    instrumentation to measure it:
    - dt_by_slot[]: last_evt_dt_us attributed to the slot it occurred in,
    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
2026-08-16 tdma: correct TOA and TX-start latency constants from measurement
    Bench measurement via the tx_evt_dt_us telemetry latch (both consoles,
    50 ms slots) showed boundary->TxDone at 8292 us on both roles exactly,
    so there is no per-role TX latency asymmetry to split constants over.
    The apparent ~1.1 ms master/secondary difference was a constant error
    propagated through sync alignment: the secondary aligned its boundary
    through the wrong constants and sat 560 us late, which cross-unit
    boundary-referenced readings picked up in full. All self-checks landed:
    secondary drx held at 7732 us (TOA_const + L_const by construction) and
    master drx 8852 us matched the predicted 560 us offset exactly.
    - TDMA_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
    [tdma.h, tdma_radio.c]
2026-08-17 docs: task write-up — make add_phase_adj accumulate (step 3, tightening sequence)
2026-08-17 tdma: make add_phase_adj accumulate pending phase corrections
    tdma_port_add_phase_adj() was named "add" but implemented set, so a
    second post landing before the next slot boundary silently discarded
    the first. Use atomic_add; slot_alarm_cb() still consumes the whole
    pending value once via atomic_clear.
    Behavior-identical for today's call pattern (tdma_core_sync_feed()
    posts once per beacon, boundaries consume 4x per frame, so never more
    than one value is outstanding). Matters once two posts can land between
    consumptions, as in the M3 filter work.
    Step 3 (first half) of the 50 ms -> 20 ms tightening sequence; write-up
    in docs/phase_adj_accumulate.md.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
    [tdma_port.c]
2026-08-17 tdma: tighten sync lock threshold to 250 us
    TDMA_SYNC_LOCK_ERR_US 1000 -> 250. Step 3 (second half) of the 50 ms ->
    20 ms tightening sequence, taken after the accumulate change soaked
    clean over 11 min on two units.
    The constant gates acquisition only: it is the bar SYNCING measures
    against to reach RUNNING, and no path leaves RUNNING once locked
    (tdma_start() is the sole entry into SYNCING), so a beacon over the
    threshold only resets lock_streak. Tightening cannot destabilise a
    running link.
    Measured basis from the soak: secondary phase_err held median 0 us,
    p95 |err| 24 us, worst 51 us, with no drift across the run, and was
    already inside +/-11 us before the first lock at +2.30 s. 250 us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
    [tdma.h]
2026-08-17 changelog: fold the lock-threshold risk finding through the document
    The 250 us change landed with its own entry; this makes the rest of the
    document agree with it.
    - Radio-layer summary said "3 beacons under 1 ms error". Now 250 us, and
    states that SYNCING -> RUNNING is one-way, so the threshold governs
    start-up alignment only.
    - Open-items list: both blockers closed, tightening sequence at step 3,
    and what actually remains before 20 ms can be called proven.
    - Known limitations: the ~5x margin is measured on two units at 50 ms.
    Records what has not been re-measured at 20 ms with four units, and
    names the failure mode the one-way transition implies -- slow or
    absent lock, not a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
2026-08-17 docs: task write-up — 20 ms slot flip + acceptance soak (step 4, tightening sequence)
2026-08-17 tdma: flip slot width to 20 ms (step 4, tightening sequence)
    TDMA_SLOT_DURATION_US 50000 -> 20000. Frame follows to 80 ms and
    SLOT_ACTIVE to 18 ms, both derived. Straight constant flip; the runtime
    slot-width selector stays a separate card.
    Pre-flight audit clear at head: every variant's slot_duration_us passes
    the macro rather than a literal (soak_run.c, tdma_app/main.c,
    tdma_console/main.c) and tdma_init() rejects a mismatch; worst in-slot
    completion 8292 us leaves 9708 us under the 18 ms SLOT_ACTIVE;
    RX_MSGQ_DEPTH was already sized for the 20 ms 4-unit case;
    SYNC_STEP_CLAMP stays 500 us, now per 80 ms frame, raising max slew
    2.5 -> 6.25 ms/s as intended.
    Width-dependent comments made ne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
    [tdma.h, tdma_port.c]
2026-08-19 tdma_console: move payload staging off the UI loop
    The 20 ms flip cut the application's staging budget from 141.7 ms to
    51.7 ms: (SLOT_COUNT-1) * SLOT_DURATION - (TX_START_LATENCY + TOA), the
    window between a unit's TxDone and the last rx_slot_slack_work() before
    its next TX. draw_soak_dynamic() clears the body with a full-width SPI
    fill and overruns that on its own, so every repaint dropped a frame's
    payload: stale_retx ran 79/224 (35%) on the first 20 ms bench run,
    against 48 in 30 minutes at 50 ms. The same cost fitted inside the 50 ms
    budget, which is why it only surfaced after the flip.
    The engine was never at risk, and that distinction is the point: dtx
    held 8249-8300 us and slot_time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
    [main.c]
2026-09-24 docs: task write-up — rev 2 shield bring-up, OLED + microSD field variant (tdma_field)
2026-09-25 tdma_field: rev 2 shield field unit (OLED + microSD)
    New firmware variant CONFIG_APP_TDMA_FIELD for the rev 2 shield: an
    SSD1306 128x64 OLED on i2c1, a microSD card on spi4, and the unchanged
    SX1262 on spi2.
    - boards/..._shield.overlay/.conf: pins traced in the shield's ODB++
    netlist and confirmed on the bench. The I2C concat buffer is sized for
    a full frame; with the 16-byte default every frame write failed. UART
    logging stays on for bring-up.
    - src/tdma_field: the TFT console's soak runner and data thread, behind a
    buttons-only cycle-menu UI. It adds a unit pick at power-on (MASTER in
    slot 0, or SEC 1-3), an SD card summary, and card-detect.
    - An 8x8 unscii font, converted mecha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
    [main.c]
2026-09-25 tdma_console: pick the unit (MASTER / SEC 1-3) at power-on
    The TX slot used to follow the role: the master in slot 0, every
    secondary in slot 1. With a third unit, two secondaries would transmit
    together in slot 1. The power-on role pick is now a unit pick with one
    button per slot, and it sets tdma_config.slot_id, the log's META slot
    and the TX records' slot. This matches tdma_field. The buttons shrink
    from 90 to 48 px so that four fit.
2026-09-25 changelog: rev 2 shield bring-up, three-unit soak, 20 ms acceptance
    - Rev 2 shield / field variant: pins, bench results (OLED, SD,
    card-detect, logging), the cycle UI, and the unit pick.
    - First three-unit soak: 0 % radio loss on every link, and locks in
    1.35 s and 2.79 s. A third 8 KB log hole (card #25) turned up, and
    card #23's first-packet garble was seen on air.
    - Folds in the 20 ms acceptance soak (Trello #6), which the slot-flip
    entry still listed as outstanding.
2026-09-25 Streamline to two unit types: TFT unit and rev 2 shield unit
    The bench runs two kinds of radio, so the tree now builds exactly those:
    TFT unit CONFIG_APP_TDMA_CONSOLE boards/..._tft.{overlay,conf}
    shield unit CONFIG_APP_TDMA_FIELD boards/..._shield.{overlay,conf}
    - Remove LoRa send (src/main.c), the telemetry console (console.c,
    radio_cfg, payload, pingpong, display.conf), the TDMA UART-shell test
    (src/tdma_app) and the UART soak harness (src/soak), along with their
    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
2026-09-25 docs: README and CHANGELOG for the two unit types
    - README rewritten around the TFT unit and the shield unit: build and
    flash lines (with --dev-id and the one-time --recover note), the
    power-on unit pick, radio parameters, rev 2 shield pins, and the
    reboot-after-SD-swap caveat.
    - CHANGELOG: a "Streamlined to two unit types" entry and a two-unit
    variant list. Retired variants' sections are marked and kept as
    history, and paths point at the moved and renamed files.

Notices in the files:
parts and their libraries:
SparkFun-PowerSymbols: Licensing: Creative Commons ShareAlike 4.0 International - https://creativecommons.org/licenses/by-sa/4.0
